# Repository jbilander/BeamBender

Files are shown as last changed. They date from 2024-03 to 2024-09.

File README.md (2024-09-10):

# BeamBender
An open source flicker fixer PCB for Amiga 1200 and 500 to be fitted under the floppy drive.

WORK IN PROGRESS, NOT FINISHED!!!

***

Rev. 1B
<br />
<a href="images/BeamBender_flicker-fixer_A1200-A500_pic11.jpg">
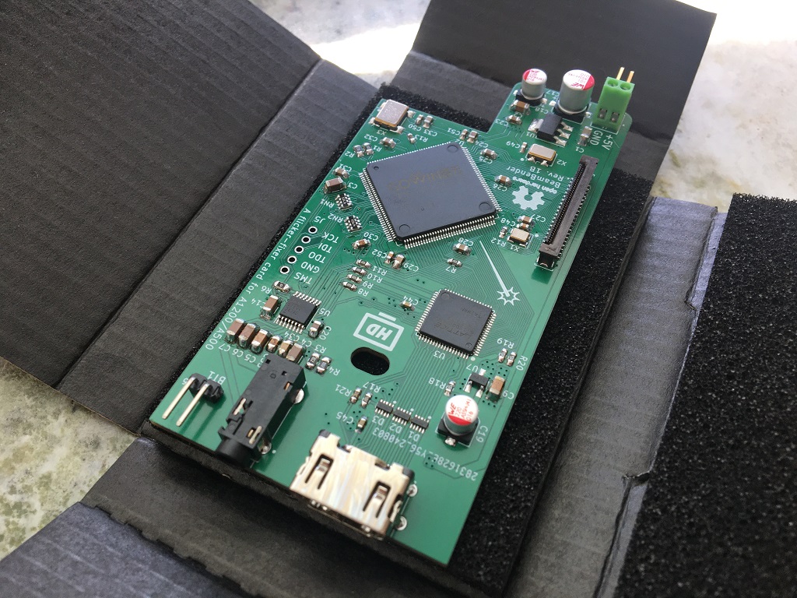
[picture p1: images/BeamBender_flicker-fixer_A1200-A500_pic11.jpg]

</a>
<a href="images/BeamBender_flicker-fixer_A1200-A500_pic12.jpg">
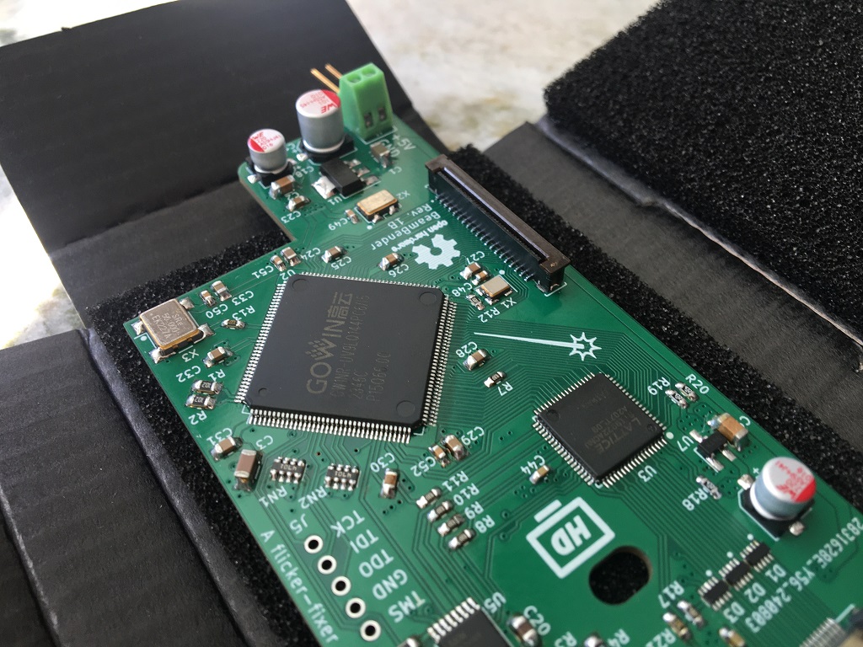
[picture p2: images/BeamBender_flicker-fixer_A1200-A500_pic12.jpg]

</a>
<br />
<a href="images/BeamBender_flicker-fixer_A1200-A500_pic13.jpg">
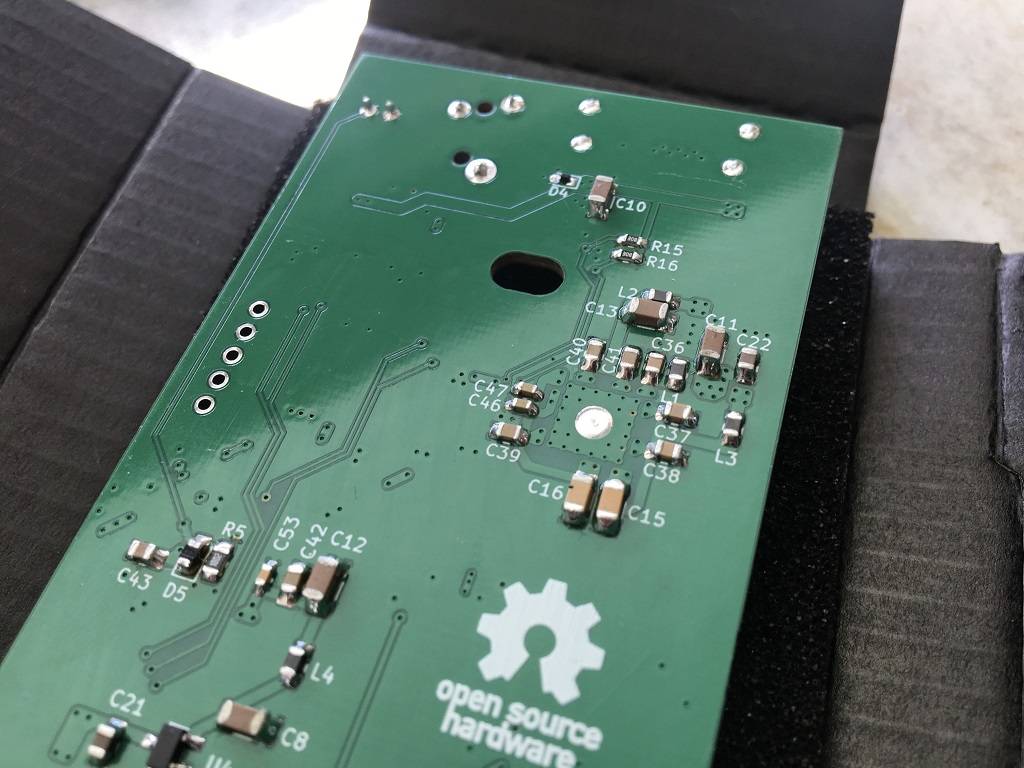
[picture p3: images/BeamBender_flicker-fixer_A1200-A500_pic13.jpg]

</a>
<a href="images/BeamBender_flicker-fixer_A1200-A500_pic14.jpg">
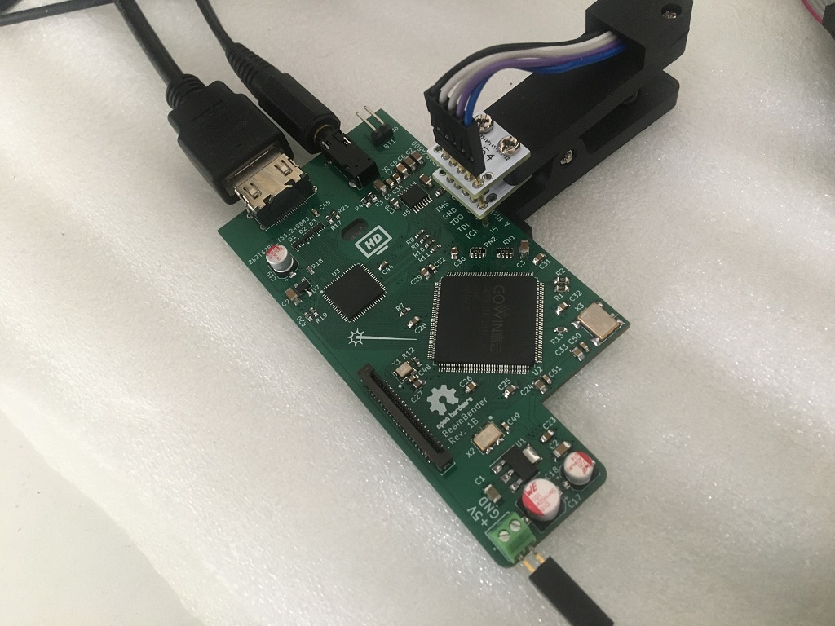
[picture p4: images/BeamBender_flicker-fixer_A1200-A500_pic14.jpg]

</a>

***

Rev. 1A
<br />
<a href="images/BeamBender_flicker-fixer_A1200-A500_pic1.png">
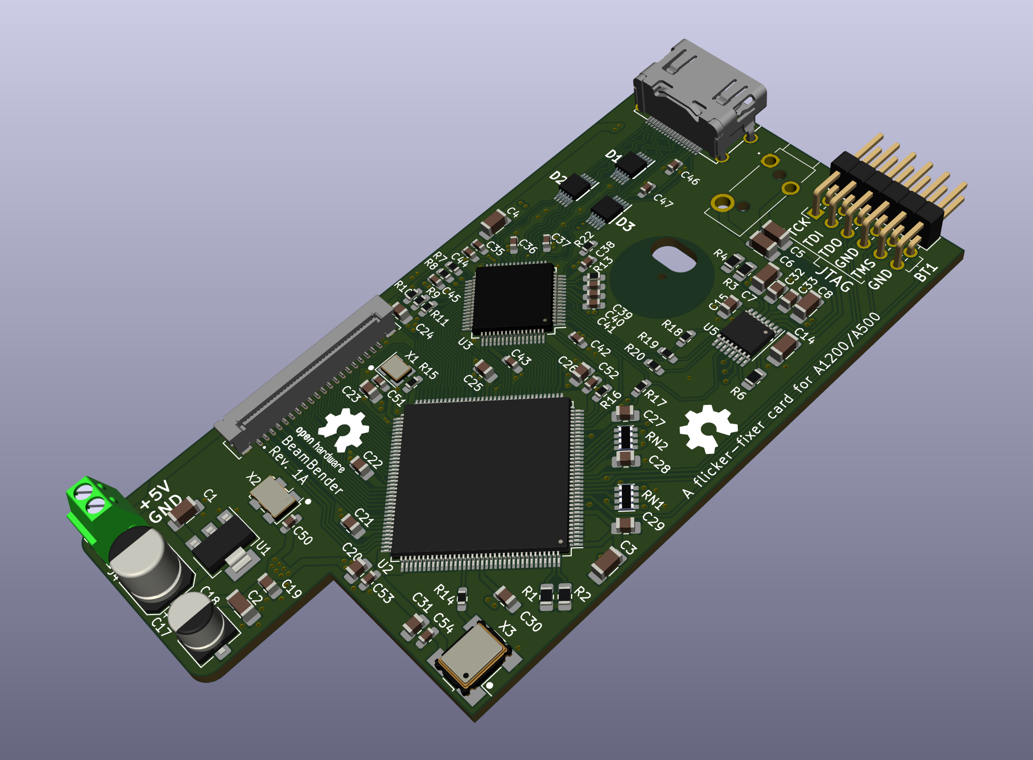
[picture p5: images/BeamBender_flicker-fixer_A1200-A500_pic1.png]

</a>
<br />
<a href="images/BeamBender_flicker-fixer_A1200-A500_pic2.png">
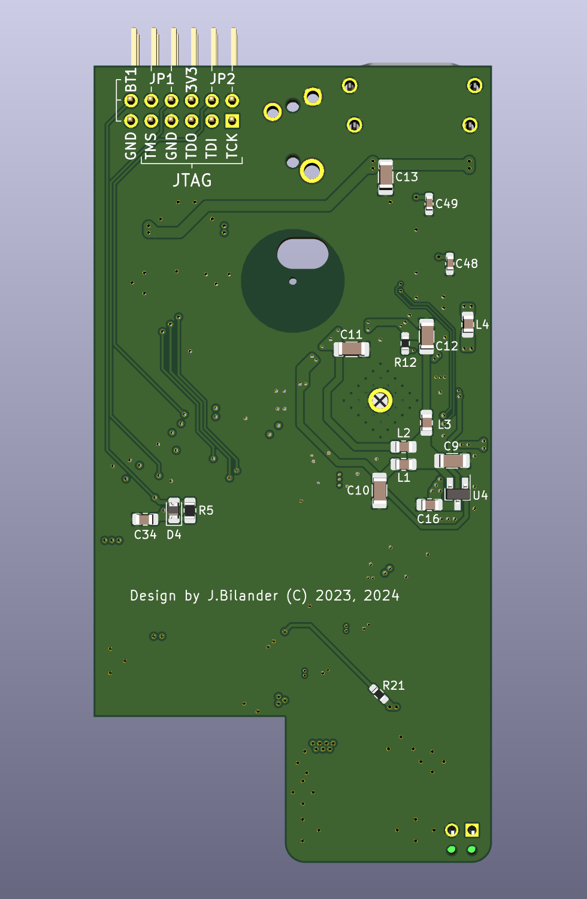
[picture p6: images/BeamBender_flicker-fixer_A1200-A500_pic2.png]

</a>
<br />
<a href="images/BeamBender_flicker-fixer_A1200-A500_pic3.jpg">
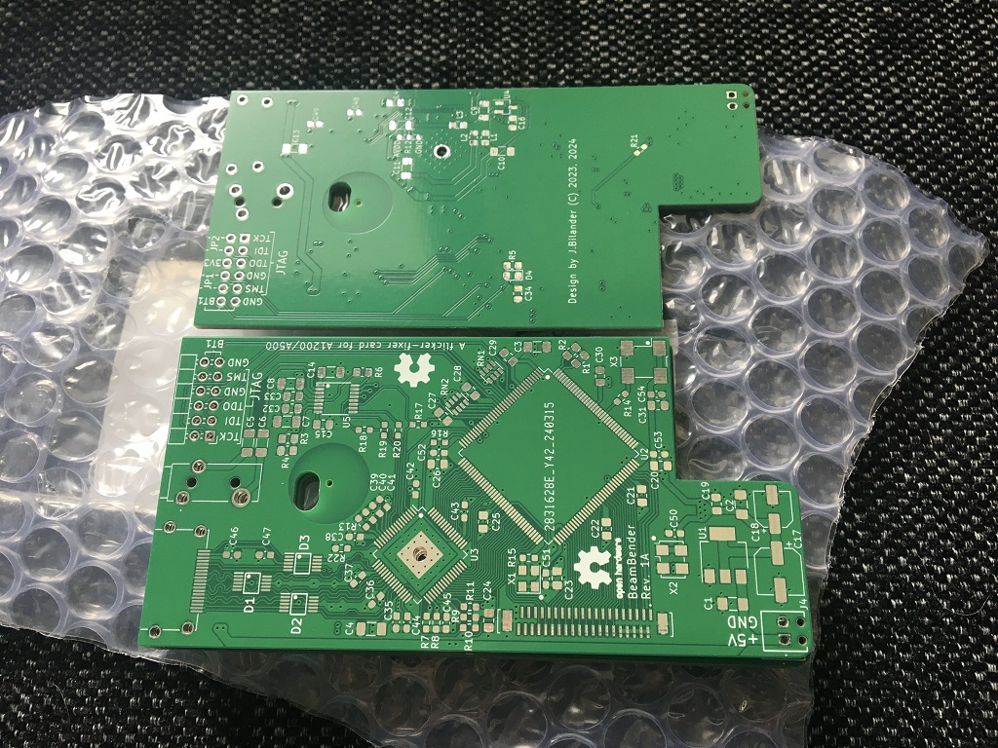
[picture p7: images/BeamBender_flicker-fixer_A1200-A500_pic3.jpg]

</a>
<br />
<a href="images/BeamBender_flicker-fixer_A1200-A500_pic4.jpg">
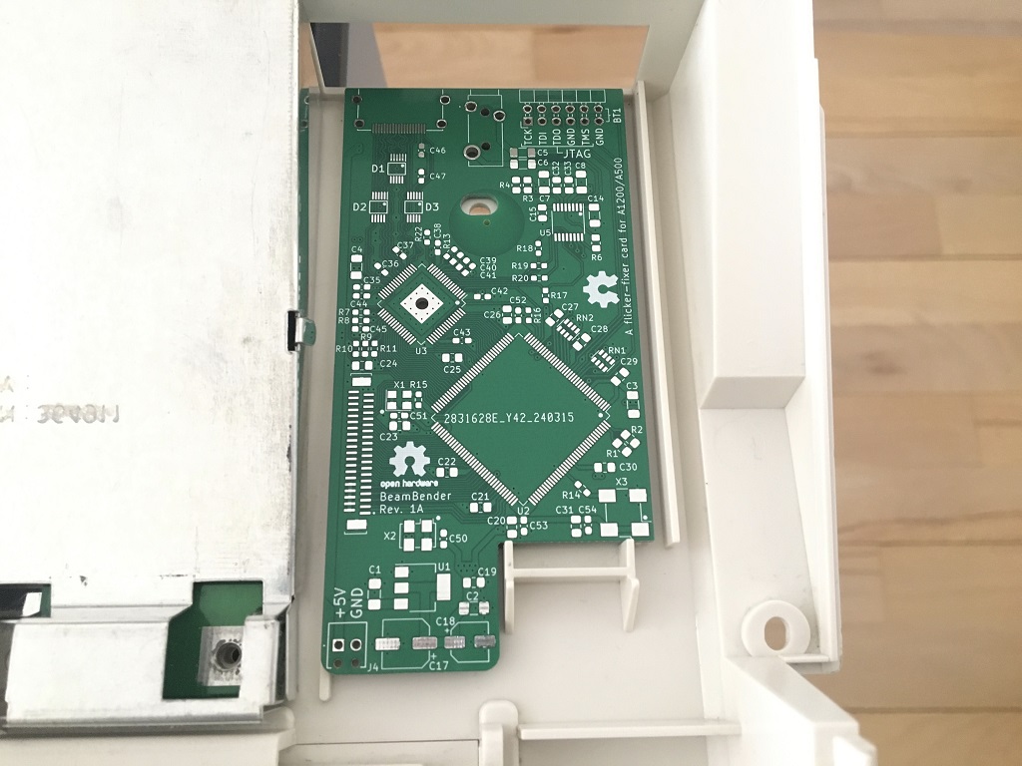
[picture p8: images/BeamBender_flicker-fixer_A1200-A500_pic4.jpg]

</a>
<br />
<a href="images/BeamBender_flicker-fixer_A1200-A500_pic5.jpg">
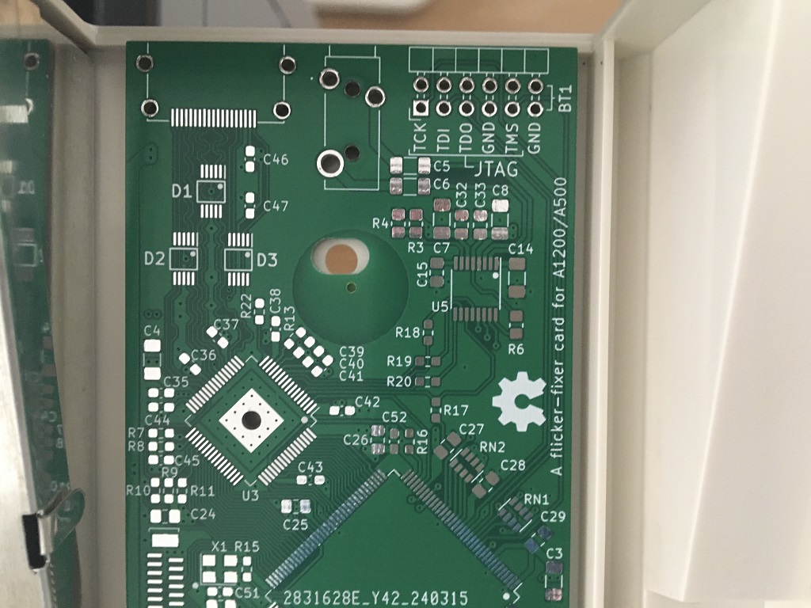
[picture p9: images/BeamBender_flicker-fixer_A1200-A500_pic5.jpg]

</a>
<a href="images/BeamBender_flicker-fixer_A1200-A500_pic6.jpg">
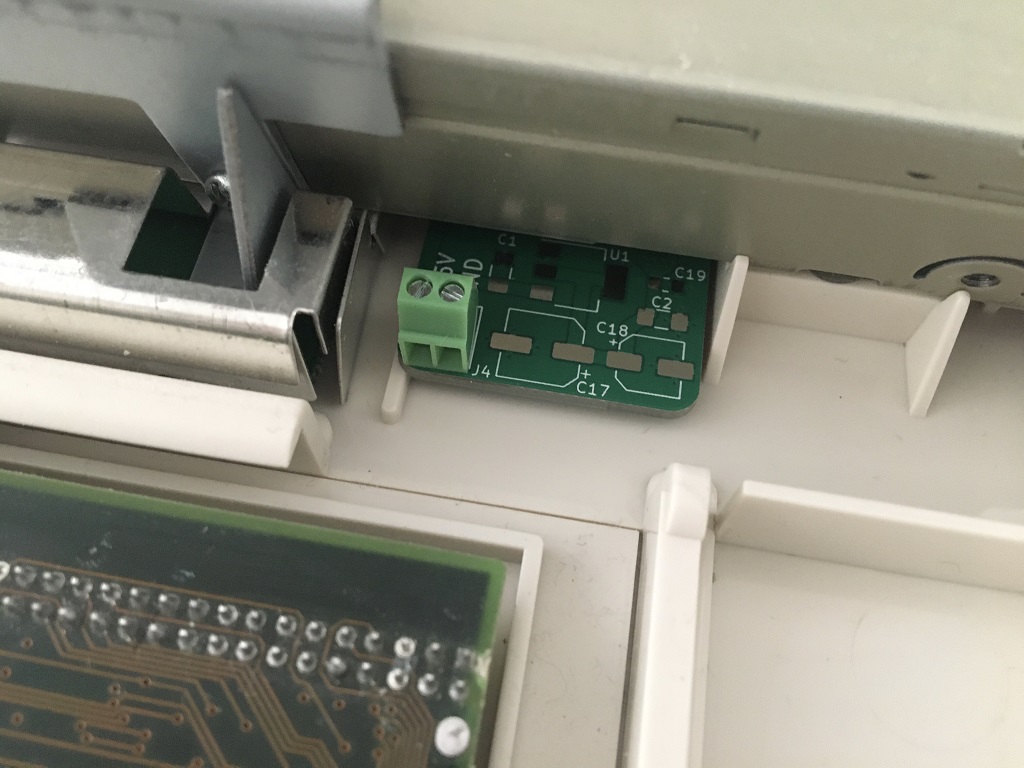
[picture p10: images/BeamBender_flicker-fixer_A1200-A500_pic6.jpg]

</a>
<br />
<a href="images/BeamBender_flicker-fixer_A1200-A500_pic7.jpg">
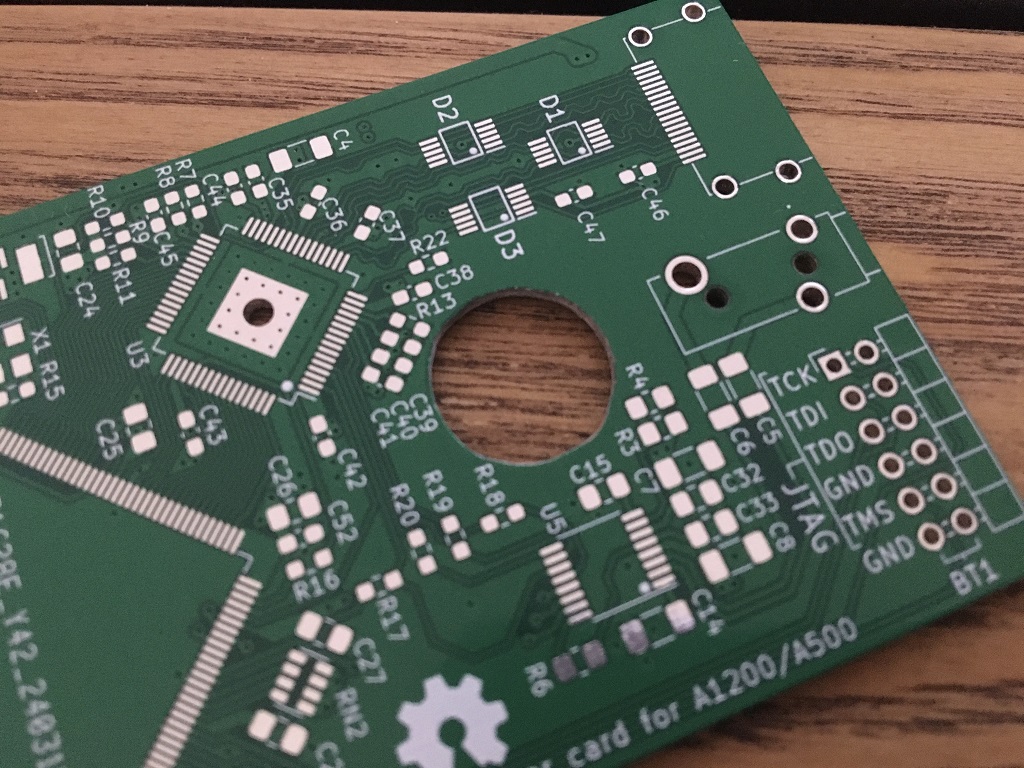
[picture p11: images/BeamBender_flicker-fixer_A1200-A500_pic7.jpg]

</a>
<a href="images/BeamBender_flicker-fixer_A1200-A500_pic8.jpg">
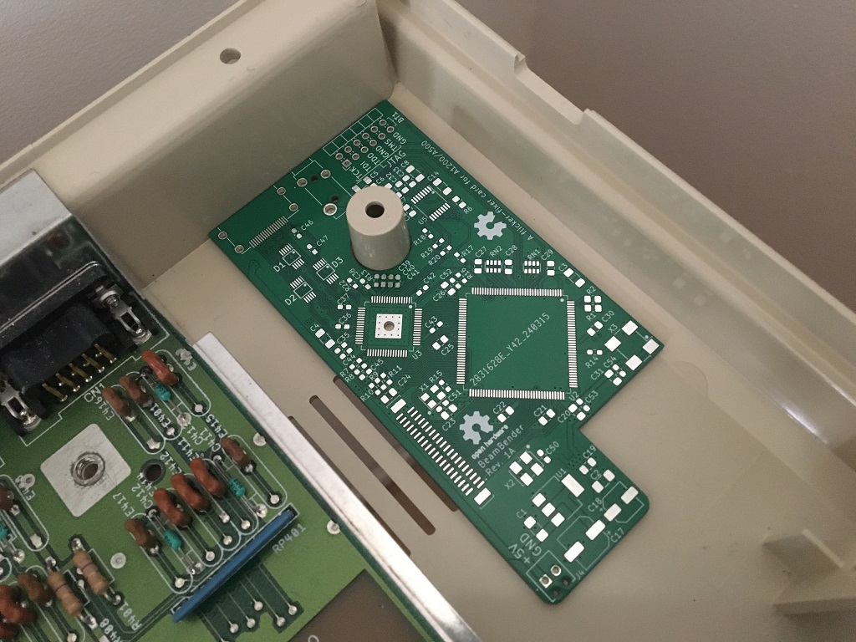
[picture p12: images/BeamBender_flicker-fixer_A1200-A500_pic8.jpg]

</a>
<br />
<a href="images/BeamBender_flicker-fixer_A1200-A500_pic9.jpg">
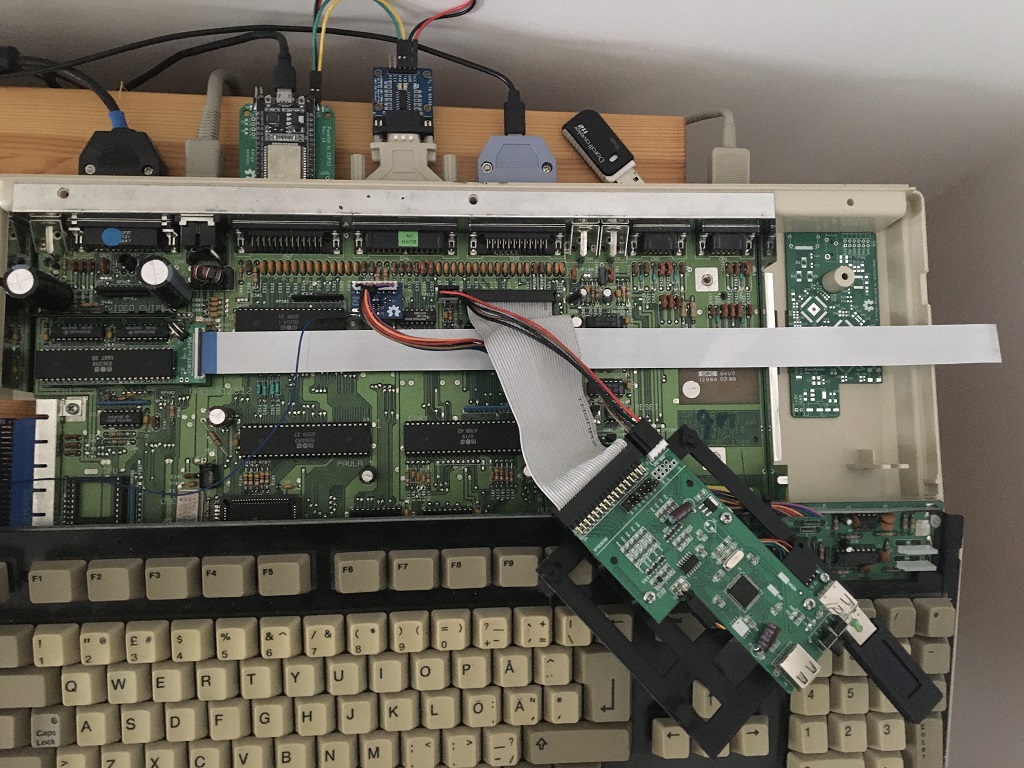
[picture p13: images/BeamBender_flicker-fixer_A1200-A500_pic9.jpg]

</a>
<a href="images/BeamBender_flicker-fixer_A1200-A500_pic10.jpg">
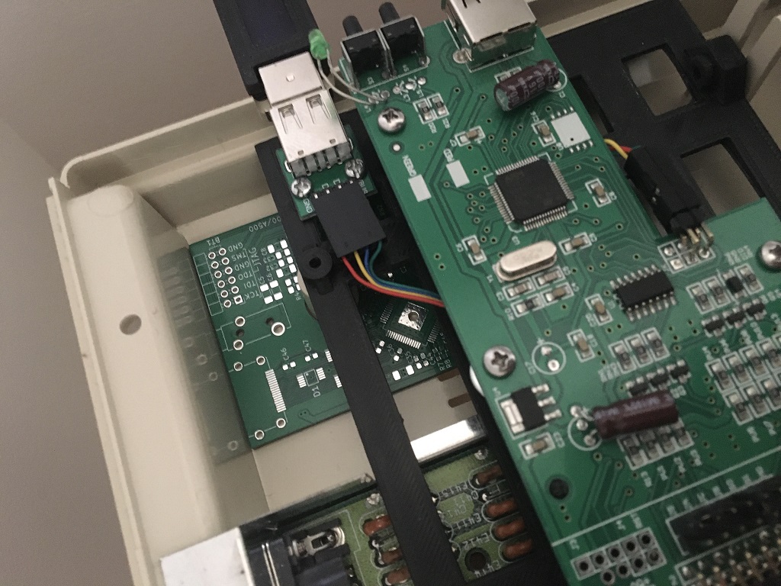
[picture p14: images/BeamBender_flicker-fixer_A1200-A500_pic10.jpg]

</a>

***

BOM Rev. 1B
---------
Designator  | Name/Value   | Package | Notes
-|-|-|-|
U1 | Voltage Regulator 3.3V, <br /> LM1117-3.3 or <br /> AMS1117-3.3 | SOT-223 | 3.3V 1A Low Drop-Out (LDO) Voltage regulator. https://www.aliexpress.com/item/32869037691.html
U2 | Gowin FPGA GW1NR-UV9LQ144PC6/I5 | LQFP-144 | FPGA - Field Programmable Gate Array, 8640 LE, 121 I/O, Embedded 64Mbit 16-bit PSRAM <br /> [GW1NR-UV9LQ144PC6/I5](https://www.mouser.com/ProductDetail/192-1NRUV9LQ144PC6I5)
U3 | SiI9022A | QFN-72-1EP_10x10mm_P0.5mm_EP4.7x4.7mm | 165 MHz High Performance HDMI Transmitter [SII9022ACNU](https://www.mouser.com/ProductDetail/842-SII9022ACNU)
U4 | Voltage Regulator 1.8V, <br /> MCP1702T-1802E/CB | SOT-23 | 1.8V Low Drop-Out (LDO) Voltage regulator. [MCP1702T1802E-CB](https://www.mouser.com/ProductDetail/579-MCP1702T1802E-CB)
U5 | Audio A/D Converter AK5720VT | TSSOP-16 | ADC IC 2ch 24bit 96K. [AK5720VT](https://www.mouser.se/ProductDetail/412-AK5720VT)
U6 | Voltage Regulator 1.2V, <br /> MCP1702T-1202E/CB | SOT-23 | 1.2V Low Drop-Out (LDO) Voltage regulator. [MCP1702T1202E-CB](https://eu.mouser.com/ProductDetail/579-MCP1702T1202E-CB)
X1 | Abracon ASE-27.000MHZ-L-R-T | XTAL OSC SMD 3.2 mm x 2.5 mm | Standard Clock Oscillator XO 27MHZ CMOS SMD [ASE-27.000MHZ-L-R-T](https://www.mouser.com/ProductDetail/815-ASE-27.000-LR-T)
X2 | Abracon ASFL1-24.576MHZ-EC-T | XTAL OSC SMD 5.0 mm x 3.2 mm | Standard Clock Oscillators 24.576 MHZ 15PF 3.3V [ASFL1-24.576MHZ-EC-T](https://www.mouser.com/ProductDetail/815-ASFL1-24.5-EC-T)
X3 | Standard Clock Oscillator 50 MHz, 3.3V LVCMOS | XTAL OSC SMD 7 mm x 5 mm | e.g. [FN5000109](https://www.mouser.com/ProductDetail/729-FN5000109) or [LH736050](https://www.mouser.com/ProductDetail/972-LH736050.000000I)
J1 | FFC & FPC Connectors .5 FPC VT ZIF Type-A | 40 Position FPC connector, Pitch 0.5 mm | [TE Connectivity 4-1734742-0](https://www.mouser.com/ProductDetail/571-4-1734742-0)
J2 | HDMI 1.4 Receptacle Connector 19 Position Surface Mount, Right Angle TH | HDMI Receptacle | [Amphenol 10029449-111RLF](https://www.mouser.com/ProductDetail/649-10029449-111RLF)
J3 | Phone Connectors 3.5 mm, Stereo | 3 Position Through Hole | [Kycon STX-3501-3N](https://www.mouser.com/ProductDetail/806-STX-3501-3N)
J4 | VCC/GND Phoenix Contact 2pin 2.54mm pitch | Fixed Terminal Blocks 2P 2.54mm 90DEG | VIN +5V <br /> Be careful with orientation, check polarity BEFORE connecting anything here. You can take +5V/GND from internal floppy pin-header on Amiga motherboard.<br />[1725656](https://www.mouser.com/ProductDetail/651-1725656) or [Aliexpress](https://www.aliexpress.com/item/1005001677869988.html)
D1-D3 | ESD Suppressors / TVS Diodes | U-DFN2510-10 | [D5V0F4U10LP-7](https://www.mouser.com/ProductDetail/621-D5V0F4U10LP-7)
D4 | ESD Suppressor / TVS Diode 1 Ch | SOD-723-2 | [SP1003-01DTG](https://www.mouser.com/ProductDetail/576-SP1003-01DTG) Optional ESD protection for VCC.
D5 | Diode - General Purpose | 0805 | e.g. [TS4148RBG](https://www.mouser.com/ProductDetail/821-TS4148RBG) Diode in RC-debounce (R5, C34) circuit for BT1 (Button 1).
L1-L4 | Ferrite Bead 600ohms 100MHz .5A Monolithic | 0805 | e.g. [HZ0805E601R-10](https://www.mouser.com/ProductDetail/875-HZ0805E601R-10)
C1-C13 | Capacitor 10uF | 1206 |
C14 | Capacitor 0.47uF | 1206 | e.g. [UMK316B7474KL-T](https://www.mouser.com/ProductDetail/963-UMK316B7474KL-T)
C15, C16 | Capacitor 0.1uF | 1206 |
C17 | Polarized Capacitor 100uF | CP_Elec_6.3x7.7 | e.g. [Wurth SMD WCAP-AS5H 100uF](https://www.mouser.com/ProductDetail/710-865230245004)
C18, C19 | Polarized Capacitor 22uF | CP_Elec_5x5.8 | e.g. [Wurth SMD WCAP-AS5H 22uF](https://www.mouser.com/ProductDetail/710-865230342002)
C20-C22 | Capacitor 1uF | 0805 |
C23-C43 | Capacitor 0.1uF = 100nF | 0805 |
C44-C47 | Capacitor 0.1uF = 100nF | 0603 |
C48-C53 | Capacitor 0.01uF = 10nF | 0603 |
R1-R3 | 1k Ω | 0805 |
R4, R5 | 10k Ω | 0805 |
R6 | 0-9 Ω or solder blob| 0805 | e.g. [CR0805-J/-000ELF](https://www.mouser.com/ProductDetail/652-CR0805-J-000ELF)
R7-R14 | 33 Ω | 0603 | e.g. [CR0603-FX-33R0ELF](https://www.mouser.com/ProductDetail/652-CR0603FX-33R0ELF)
R15, R16 | 2k Ω | 0603 | e.g. [CR0603-FX-2001ELF](https://www.mouser.com/ProductDetail/652-CR0603-FX-2001LF)
R17 | 4.3k Ω, 1% tolerance | 0603 | e.g. [CR0603-FX-4301ELF](https://www.mouser.com/ProductDetail/652-CR0603FX-4301ELF) The recommended value is 4.3k Ω ±1% with internal source termination enabled and 5.1k Ω ±1% without internal source termination. 
R18-R20 | 4.7k Ω | 0603 | 
R21 | 10k Ω | 0603 |
RN1, RN2 | CAY16A-4701F4LF RES ARRAY 4 Resistors 4.7k Ω | 1206 | [CAY16A-4701F4LF](https://eu.mouser.com/ProductDetail/652-CAY16A-4701F4LF)

***

[][cc-by-sa]

This work is licensed under a
[Creative Commons Attribution-ShareAlike 4.0 International License][cc-by-sa].

[][cc-by-sa]

[cc-by-sa]: http://creativecommons.org/licenses/by-sa/4.0/
[cc-by-sa-image]: https://licensebuttons.net/l/by-sa/4.0/88x31.png
[cc-by-sa-shield]: https://img.shields.io/badge/License-CC%20BY--SA%204.0-lightgrey.svg

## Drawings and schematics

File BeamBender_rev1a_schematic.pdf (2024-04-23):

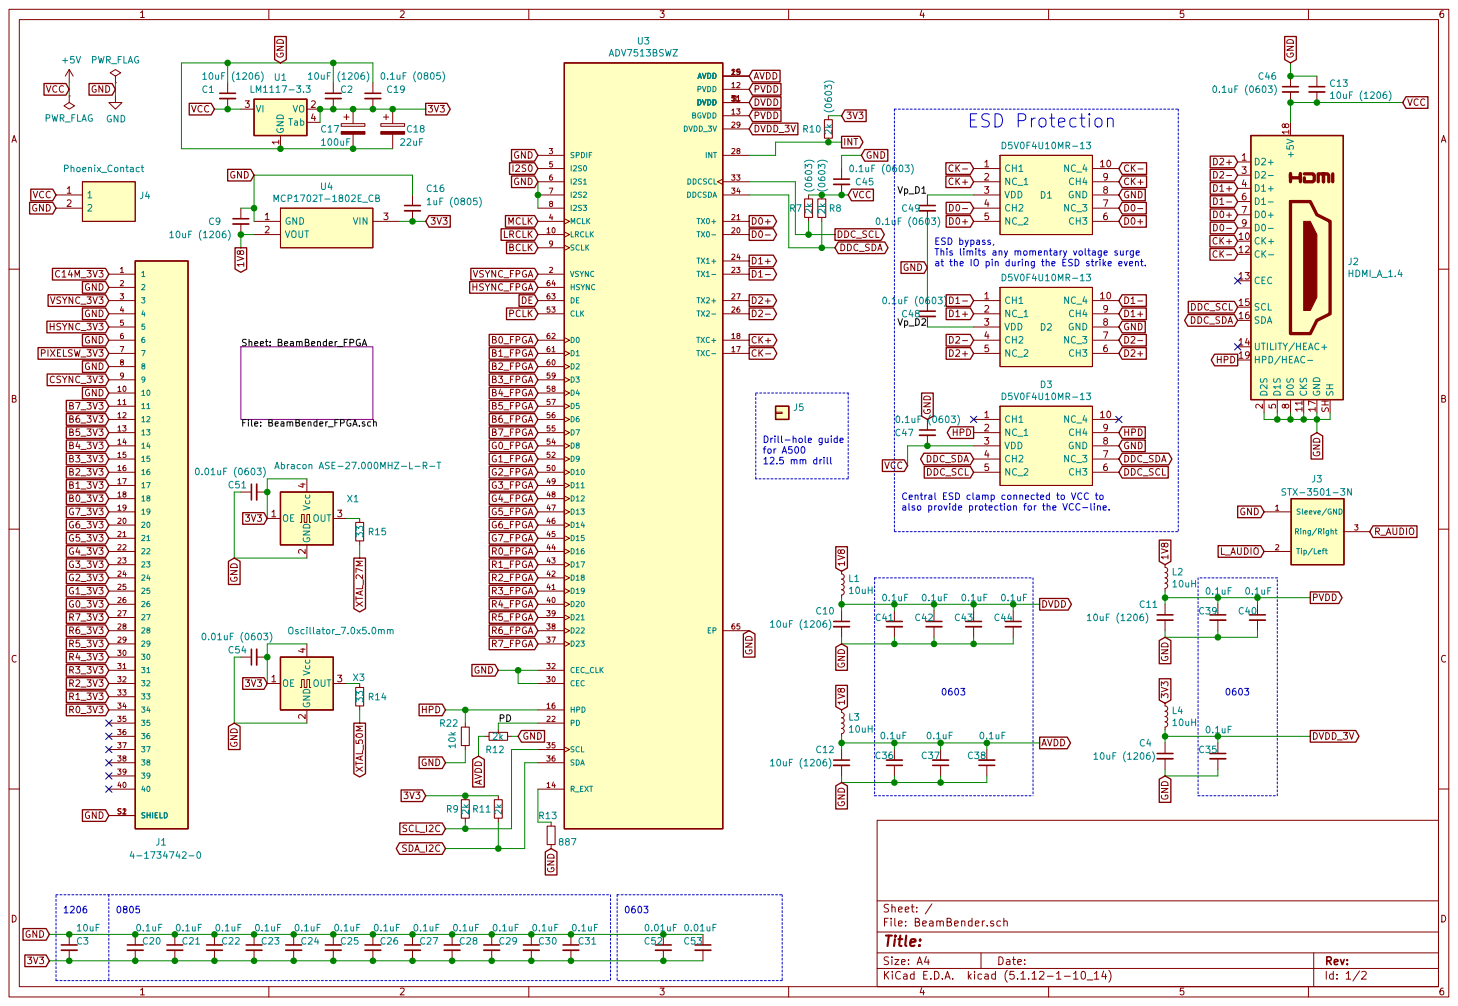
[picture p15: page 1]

This limits any momentary voltage surge
at the IO pin during the ESD strike event.
0.1uFC48

2 OUT 3 Vcc 4 X1 Abracon ASE-27.000MHZ-L-R-TC27

also provide protection for the VCC-line.

Id: 1/2 Title: File: BeamBender.sch Sheet: /

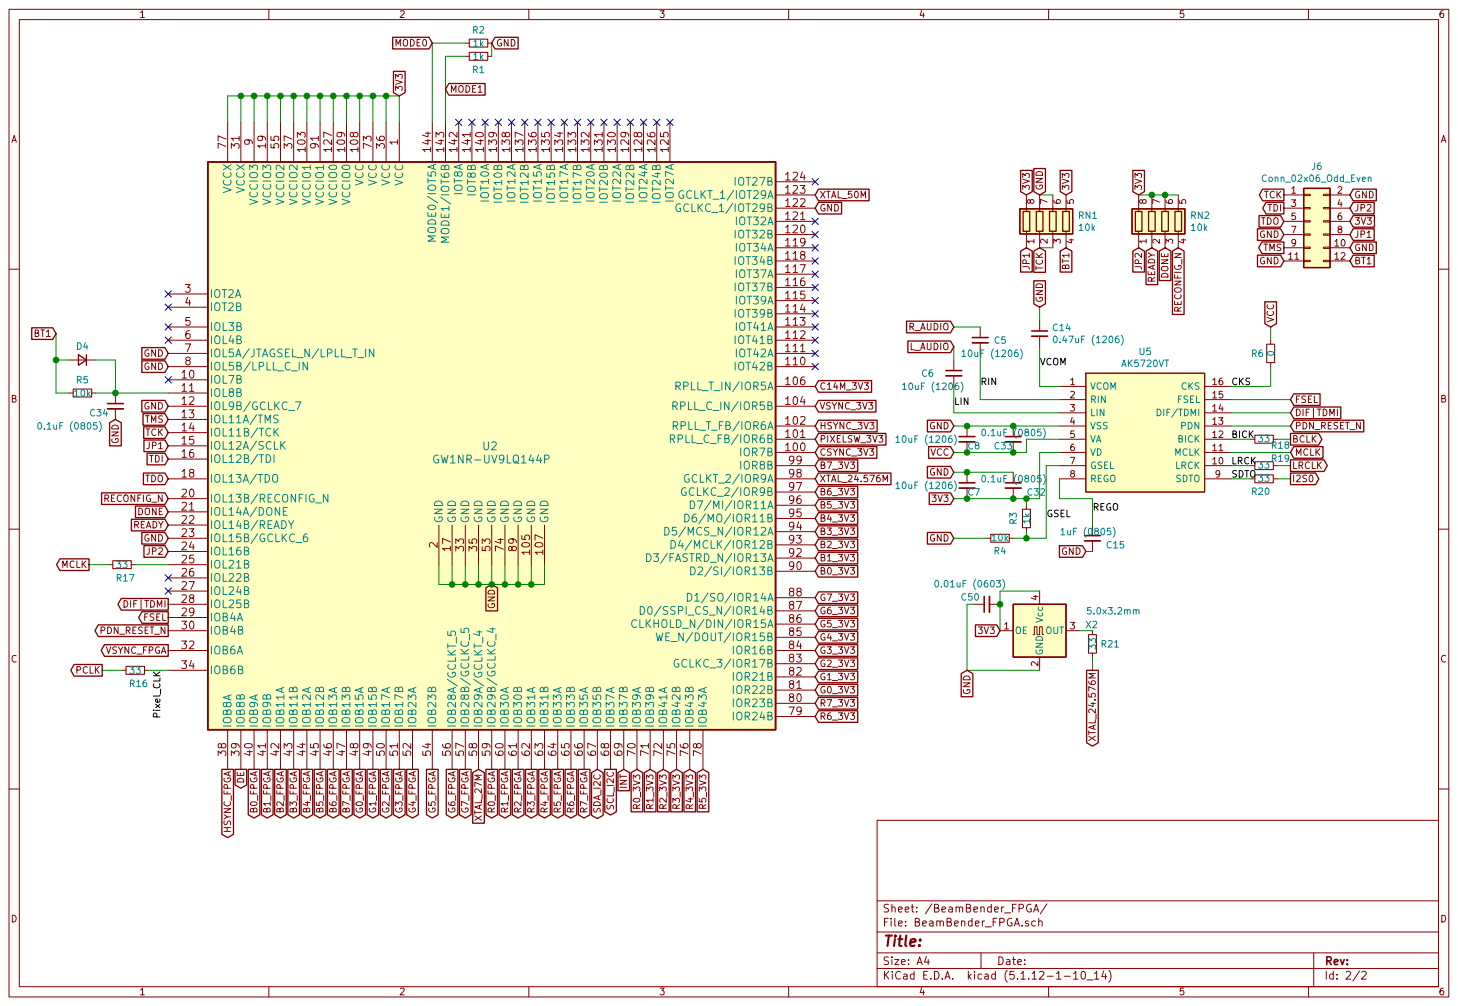
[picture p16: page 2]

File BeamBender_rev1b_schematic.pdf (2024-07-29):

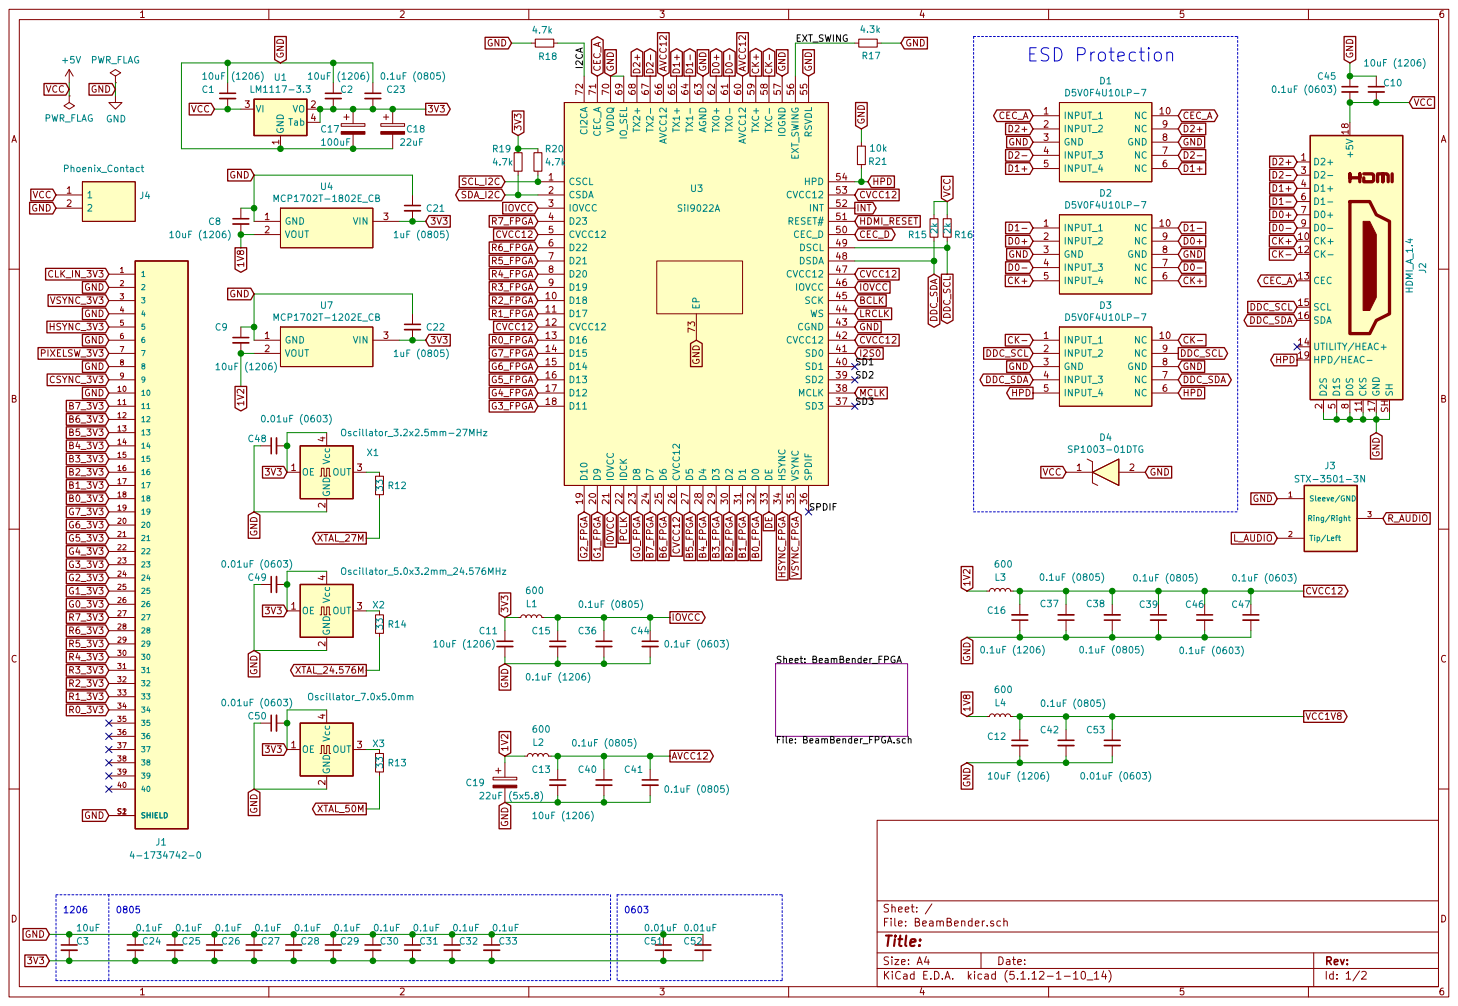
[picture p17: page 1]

Id: 1/2 Title: File: BeamBender.sch Sheet: / Sheet: BeamBender_FPGA

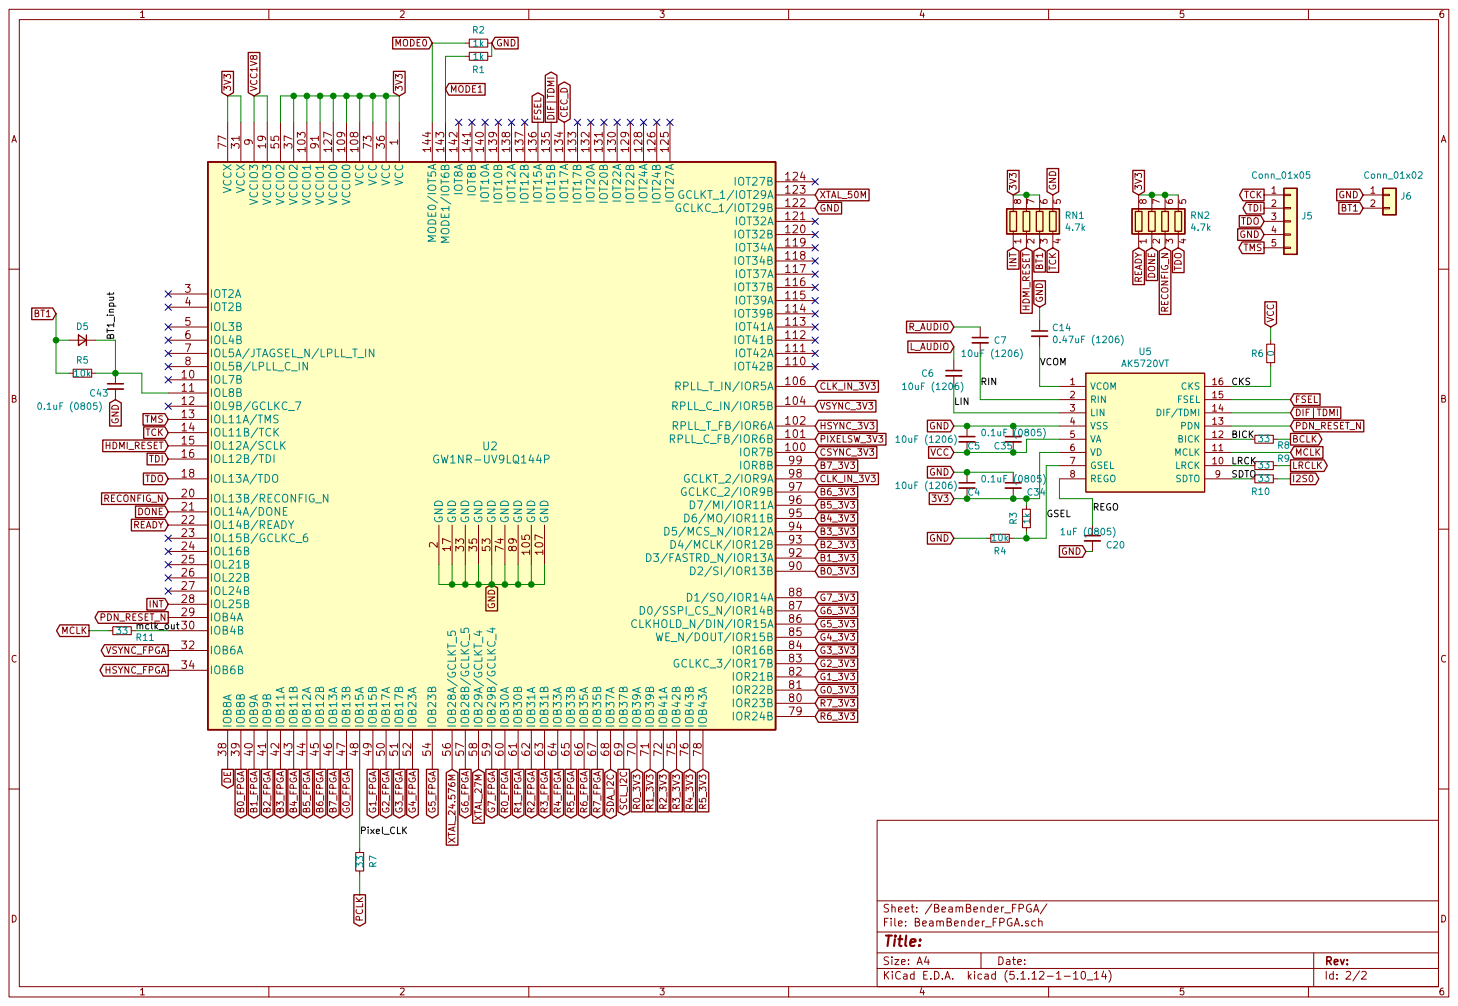
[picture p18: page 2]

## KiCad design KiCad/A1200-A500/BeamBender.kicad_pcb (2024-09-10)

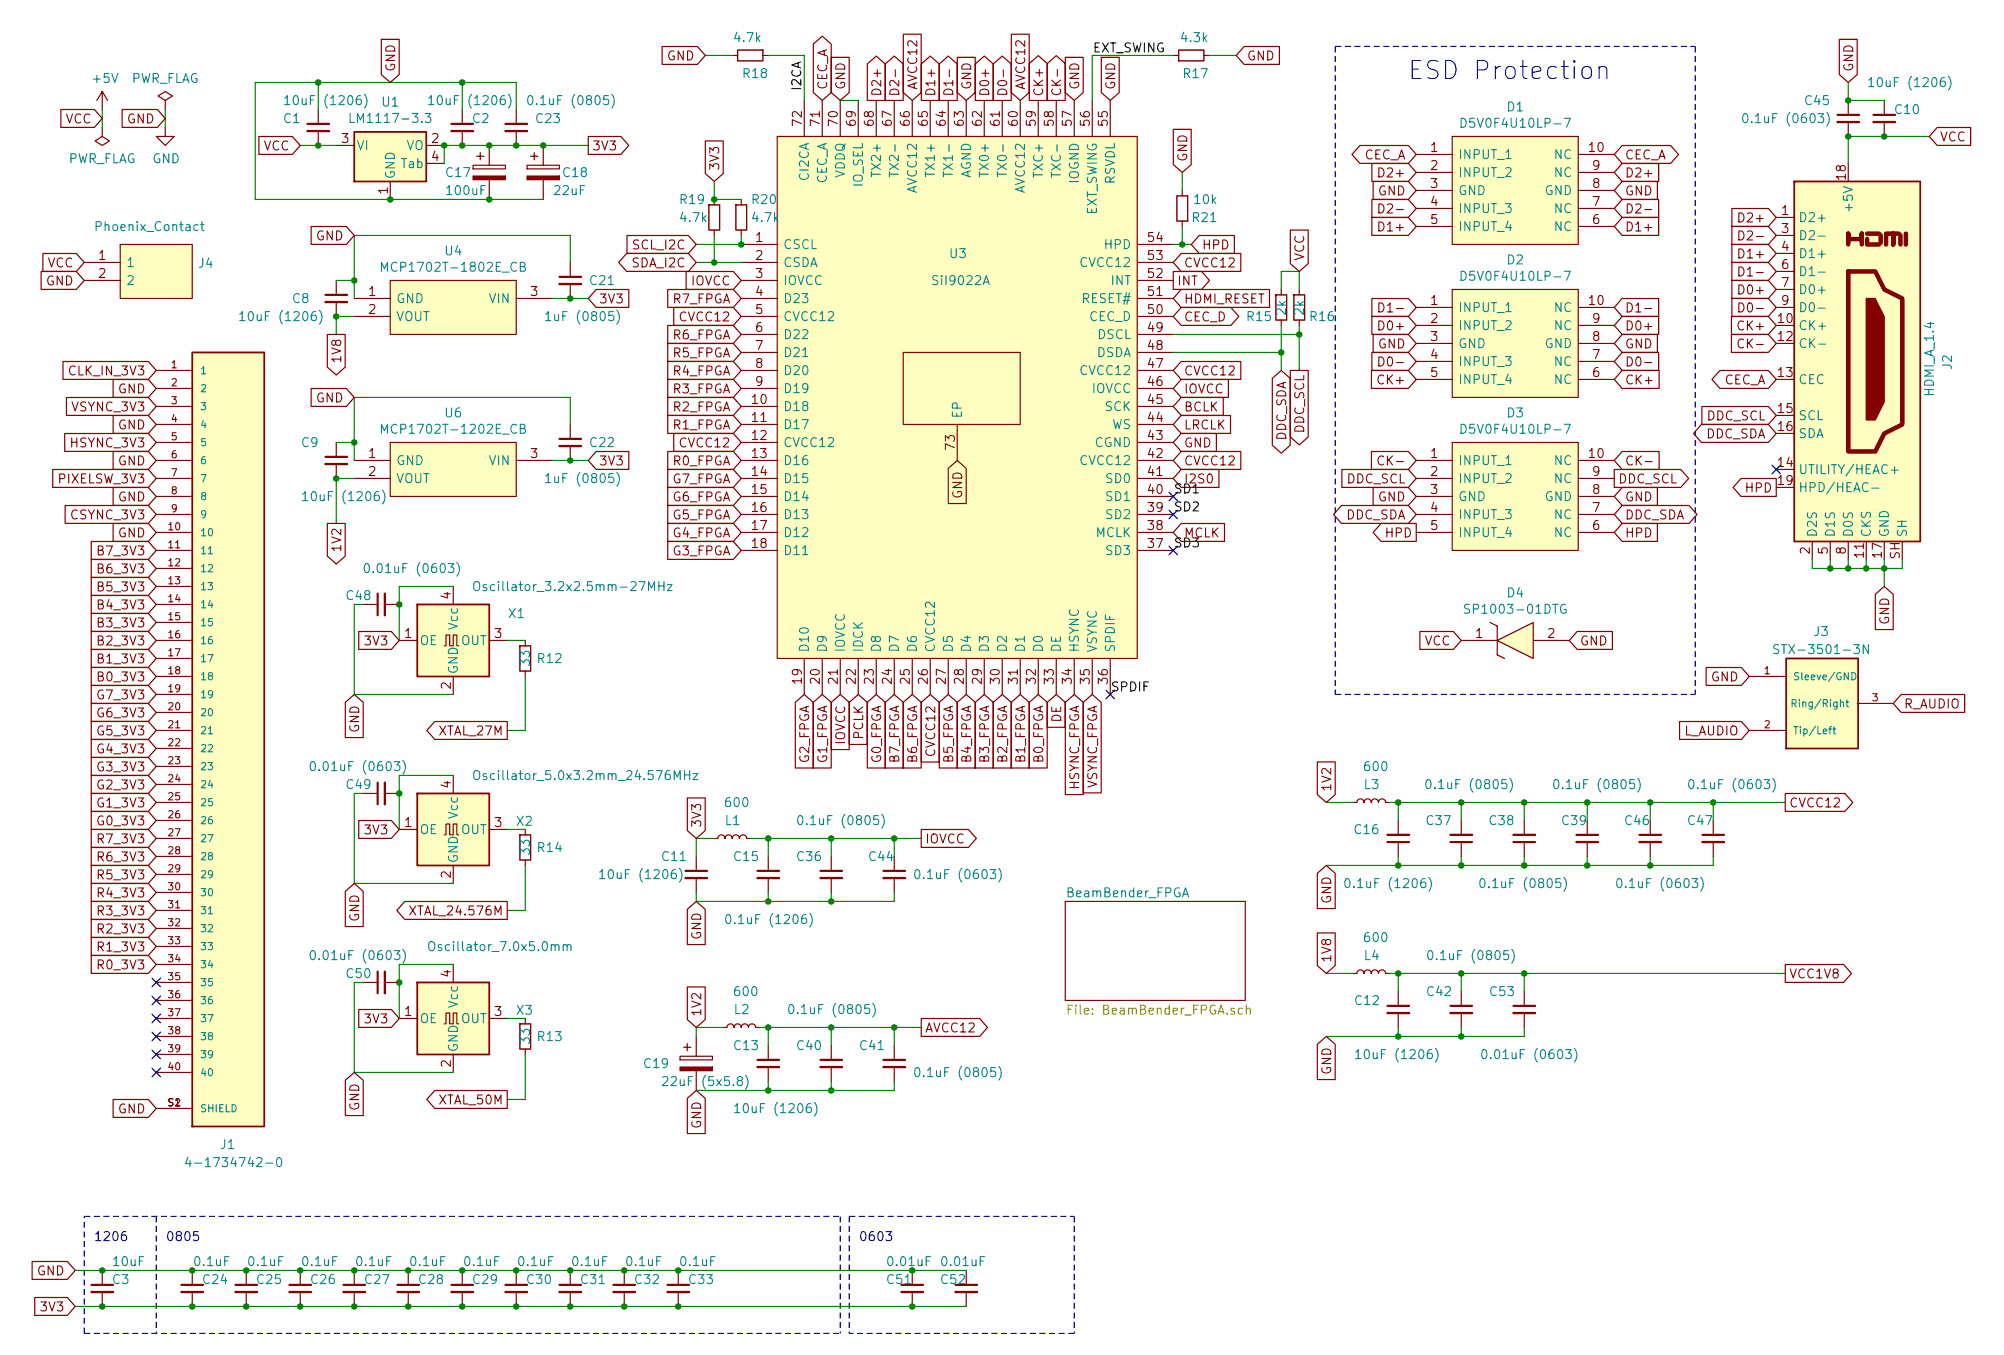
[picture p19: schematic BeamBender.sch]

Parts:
C1, C2: 10uF (1206); C_1206_3216Metric_Pad1.42x1.75mm_HandSolder
C3: 10uF; C_1206_3216Metric_Pad1.33x1.80mm_HandSolder
C8, C9, C10, C11, C12, C13: 10uF (1206); C_1206_3216Metric_Pad1.33x1.80mm_HandSolder
C15, C16: 0.1uF (1206); C_1206_3216Metric_Pad1.33x1.80mm_HandSolder
C17: 100uF; CP_Elec_6.3x7.7
C18: 22uF; CP_Elec_5x5.8
C19: 22uF (5x5.8); CP_Elec_5x5.8
C21, C22: 1uF (0805); C_0805_2012Metric_Pad1.18x1.45mm_HandSolder
C23: 0.1uF (0805); C_0805_2012Metric_Pad1.15x1.40mm_HandSolder
C24, C25, C26, C27, C28, C29, C30, C31, C32, C33: 0.1uF; C_0805_2012Metric_Pad1.18x1.45mm_HandSolder
C36, C37, C38, C39, C40, C41, C42: 0.1uF (0805); C_0805_2012Metric_Pad1.18x1.45mm_HandSolder
C44, C45, C46, C47: 0.1uF (0603); C_0603_1608Metric_Pad1.08x0.95mm_HandSolder
C48, C49, C50, C53: 0.01uF (0603); C_0603_1608Metric_Pad1.08x0.95mm_HandSolder
C51, C52: 0.01uF; C_0603_1608Metric_Pad1.08x0.95mm_HandSolder
D1, D2, D3: D5V0F4U10LP-7; Diodes_UDFN-10_1.0x2.5mm_P0.5mm_HandSolder
D4: SP1003-01DTG; D_0603_1608Metric
J1: 4-1734742-0; TE_4-1734742-0; PARTREV P
J2: HDMI_A_1.4; HDMI-10029449-111RLF
J3: STX-3501-3N; STX35013N
J4: Phoenix_Contact
L1, L2, L3, L4: 600; L_0805_2012Metric_Pad1.15x1.40mm_HandSolder
R12, R13, R14: 33; R_0603_1608Metric_Pad0.98x0.95mm_HandSolder
R15, R16: 2k; R_0603_1608Metric_Pad0.98x0.95mm_HandSolder
R17: 4.3k; R_0603_1608Metric_Pad0.98x0.95mm_HandSolder
R18, R19, R20: 4.7k; R_0603_1608Metric_Pad0.98x0.95mm_HandSolder
R21: 10k; R_0603_1608Metric_Pad0.98x0.95mm_HandSolder
U1: LM1117-3.3; SOT-223
U3: SiI9022A; QFN-72-1EP_10x10mm_P0.5mm_EP6x6mm_ThermalVias_HandSolder
U4: MCP1702T-1802E_CB; SOT-23_Handsoldering
U6: MCP1702T-1202E_CB; SOT-23_Handsoldering
X1: Oscillator_3.2x2.5mm-27MHz; Oscillator_SMD_SeikoEpson_SG8002CE-4Pin_3.2x2.5mm
X2: Oscillator_5.0x3.2mm_24.576MHz; Oscillator_SMD_TXC_7C-4Pin_5.0x3.2mm_HandSoldering
X3: Oscillator_7.0x5.0mm; Oscillator_SMD_SeikoEpson_SG8002CA-4Pin_7.0x5.0mm_HandSolde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

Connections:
1V2: C9.2, C19.1, L2.1, L3.1, U6.2 (VOUT)
1V8: C8.2, L4.1, U4.2 (VOUT)
3V3: C2.2, C3.2, C11.1, C17.1, C18.1, C21.2, C22.2, C23.2, C24.2, C25.2, C26.2, C27.2, C28.2, C29.2, C30.2, C31.2, C32.2, C33.2, C48.2, C49.2, C50.2, C51.2, C52.2, L1.1, R19.1, R20.1, U1.2 (VO), U1.4 (Tab), U4.3 (VIN), U6.3 (VIN), X1.1 (OE), X1.4 (Vcc), X2.1 (OE), X2.4 (Vcc), X3.1 (OE), X3.4 (Vcc); also elsewhere on the board
/EXT_SWING: R17.1, U3.56 (EXT_SWING)
/I2CA: R18.1, U3.72 (CI2CA)
/SD1: U3.40 (SD1)
/SD2: U3.39 (SD2)
/SD3: U3.37 (SD3)
/SPDIF: U3.36 (SPDIF)
AVCC12: C13.1, C40.1, C41.1, L2.2, U3.60 (AVCC12), U3.66 (AVCC12)
B0_3V3: J1.18; also elsewhere on the board
B0_FPGA: U3.32 (D0); also elsewhere on the board
B1_3V3: J1.17; also elsewhere on the board
B1_FPGA: U3.31 (D1); also elsewhere on the board
B2_3V3: J1.16; also elsewhere on the board
B2_FPGA: U3.30 (D2); also elsewhere on the board
B3_3V3: J1.15; also elsewhere on the board
B3_FPGA: U3.29 (D3); also elsewhere on the board
B4_3V3: J1.14; also elsewhere on the board
B4_FPGA: U3.28 (D4); also elsewhere on the board
B5_3V3: J1.13; also elsewhere on the board
B5_FPGA: U3.27 (D5); also elsewhere on the board
B6_3V3: J1.12; also elsewhere on the board
B6_FPGA: U3.25 (D6); also elsewhere on the board
B7_3V3: J1.11; also elsewhere on the board
B7_FPGA: U3.24 (D7); also elsewhere on the board
BCLK: U3.45 (SCK); also elsewhere on the board
CEC_A: D1.1 (INPUT_1), D1.10 (NC), J2.13 (CEC), U3.71 (CEC_A)
CEC_D: U3.50 (CEC_D); also elsewhere on the board
CK+: D2.5 (INPUT_4), D2.6 (NC), J2.10 (CK+), U3.59 (TXC+)
CK-: D3.1 (INPUT_1), D3.10 (NC), J2.12 (CK-), U3.58 (TXC-)
CLK_IN_3V3: J1.1; also elsewhere on the board
CSYNC_3V3: J1.9; also elsewhere on the board
CVCC12: C16.2, C37.2, C38.2, C39.1, C46.1, C47.1, L3.2, U3.5 (CVCC12), U3.12 (CVCC12), U3.26 (CVCC12), U3.42 (CVCC12), U3.47 (CVCC12), U3.53 (CVCC12)
D0+: D2.2 (INPUT_2), D2.9 (NC), J2.7 (D0+), U3.62 (TX0+)
D0-: D2.4 (INPUT_3), D2.7 (NC), J2.9 (D0-), U3.61 (TX0-)
D1+: D1.5 (INPUT_4), D1.6 (NC), J2.4 (D1+), U3.65 (TX1+)
D1-: D2.1 (INPUT_1), D2.10 (NC), J2.6 (D1-), U3.64 (TX1-)
D2+: D1.2 (INPUT_2), D1.9 (NC), J2.1 (D2+), U3.68 (TX2+)
D2-: D1.4 (INPUT_3), D1.7 (NC), J2.3 (D2-), U3.67 (TX2-)
DDC_SCL: D3.2 (INPUT_2), D3.9 (NC), J2.15 (SCL), R16.2, U3.49 (DSCL)
DDC_SDA: D3.4 (INPUT_3), D3.7 (NC), J2.16 (SDA), R15.2, U3.48 (DSDA)
DE: U3.33 (DE); also elsewhere on the board
G0_3V3: J1.26; also elsewhere on the board
G0_FPGA: U3.23 (D8); also elsewhere on the board
G1_3V3: J1.25; also elsewhere on the board
G1_FPGA: U3.20 (D9); also elsewhere on the board
G2_3V3: J1.24; also elsewhere on the board
G2_FPGA: U3.19 (D10); also elsewhere on the board
G3_3V3: J1.23; also elsewhere on the board
G3_FPGA: U3.18 (D11); also elsewhere on the board
G4_3V3: J1.22; also elsewhere on the board
G4_FPGA: U3.17 (D12); also elsewhere on the board
G5_3V3: J1.21; also elsewhere on the board
G5_FPGA: U3.16 (D13); also elsewhere on the board
G6_3V3: J1.20; also elsewhere on the board
G6_FPGA: U3.15 (D14); also elsewhere on the board
G7_3V3: J1.19; also elsewhere on the board
G7_FPGA: U3.14 (D15); also elsewhere on the board
GND: C1.1, C2.1, C3.1, C8.1, C9.1, C10.1, C11.2, C12.2, C13.2, C15.2, C16.1, C17.2, C18.2, C19.2, C21.1, C22.1, C23.1, C24.1, C25.1, C26.1, C27.1, C28.1, C29.1, C30.1, C31.1, C32.1, C33.1, C36.2, C37.1, C38.1, C39.2, C40.2, C41.2, C42.2, C44.2, C45.1, C46.2, C47.2, C48.1, C49.1, C50.1, C51.1, C52.1, C53.2, D1.3 (GND), D1.8 (GND), D2.3 (GND), D2.8 (GND), D3.3 (GND), D3.8 (GND), D4.2, J1.2, J1.4, J1.6, J1.8, J1.10, J1.S1 (SHIELD), J1.S2 (SHIELD), J2.2 (D2S), J2.5 (D1S), J2.8 (D0S), J2.11 (CKS), J2.17 (GND), J2.SH, J3.1 (Sleeve/GND), J4.2, R17.2, R18.2, R21.2, U1.1 (GND), U3.43 (CGND), U3.55 (RSVDL), U3.57 (IOGND), U3.63 (AGND), U3.69 (IO_SEL), U3.70 (VDDQ), U3.73 (EP), U4.1 (GND), U6.1 (GND), X1.2 (GND), X2.2 (GND), X3.2 (GND); also elsewhere on the board
HDMI_RESET: U3.51 (RESET#); also elsewhere on the board
HPD: D3.5 (INPUT_4), D3.6 (NC), J2.19 (HPD/HEAC-), R21.1, U3.54 (HPD)
HSYNC_3V3: J1.5; also elsewhere on the board
HSYNC_FPGA: U3.34 (HSYNC); also elsewhere on the board
I2S0: U3.41 (SD0); also elsewhere on the board
INT: U3.52 (INT); also elsewhere on the board
IOVCC: C15.1, C36.1, C44.1, L1.2, U3.3 (IOVCC), U3.21 (IOVCC), U3.46 (IOVCC)
LRCLK: U3.44 (WS); also elsewhere on the board
L_AUDIO: J3.2 (Tip/Left); also elsewhere on the board
MCLK: U3.38 (MCLK); also elsewhere on the board
unnamed: R12.1, X1.3 (OUT)
unnamed: R13.1, X3.3 (OUT)
unnamed: R14.1, X2.3 (OUT)
PCLK: U3.22 (IDCK); also elsewhere on the board
PIXELSW_3V3: J1.7; also elsewhere on the board
R0_3V3: J1.34; also elsewhere on the board
R0_FPGA: U3.13 (D16); also elsewhere on the board
R1_3V3: J1.33; also elsewhere on the board
R1_FPGA: U3.11 (D17); also elsewhere on the board
R2_3V3: J1.32; also elsewhere on the board
R2_FPGA: U3.10 (D18); also elsewhere on the board
R3_3V3: J1.31; also elsewhere on the board
R3_FPGA: U3.9 (D19); also elsewhere on the board
R4_3V3: J1.30; also elsewhere on the board
R4_FPGA: U3.8 (D20); also elsewhere on the board
R5_3V3: J1.29; also elsewhere on the board
R5_FPGA: U3.7 (D21); also elsewhere on the board
R6_3V3: J1.28; also elsewhere on the board
R6_FPGA: U3.6 (D22); also elsewhere on the board
R7_3V3: J1.27; also elsewhere on the board
R7_FPGA: U3.4 (D23); also elsewhere on the board
R_AUDIO: J3.3 (Ring/Right); also elsewhere on the board
SCL_I2C: R20.2, U3.1 (CSCL); also elsewhere on the board
SDA_I2C: R19.2, U3.2 (CSDA); also elsewhere on the board
VCC: C1.2, C10.2, C45.2, D4.1, J2.18 (+5V), J4.1, R15.1, R16.1, U1.3 (VI); also elsewhere on the board
VCC1V8: C12.1, C42.1, C53.1, L4.2; also elsewhere on the board
VSYNC_3V3: J1.3; also elsewhere on the board
VSYNC_FPGA: U3.35 (VSYNC); also elsewhere on the board
XTAL_24.576M: R14.2; also elsewhere on the board
XTAL_27M: R12.2; also elsewhere on the board
XTAL_50M: R13.2; also elsewhere on the board

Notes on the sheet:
ESD Protection
0805
0603
1206

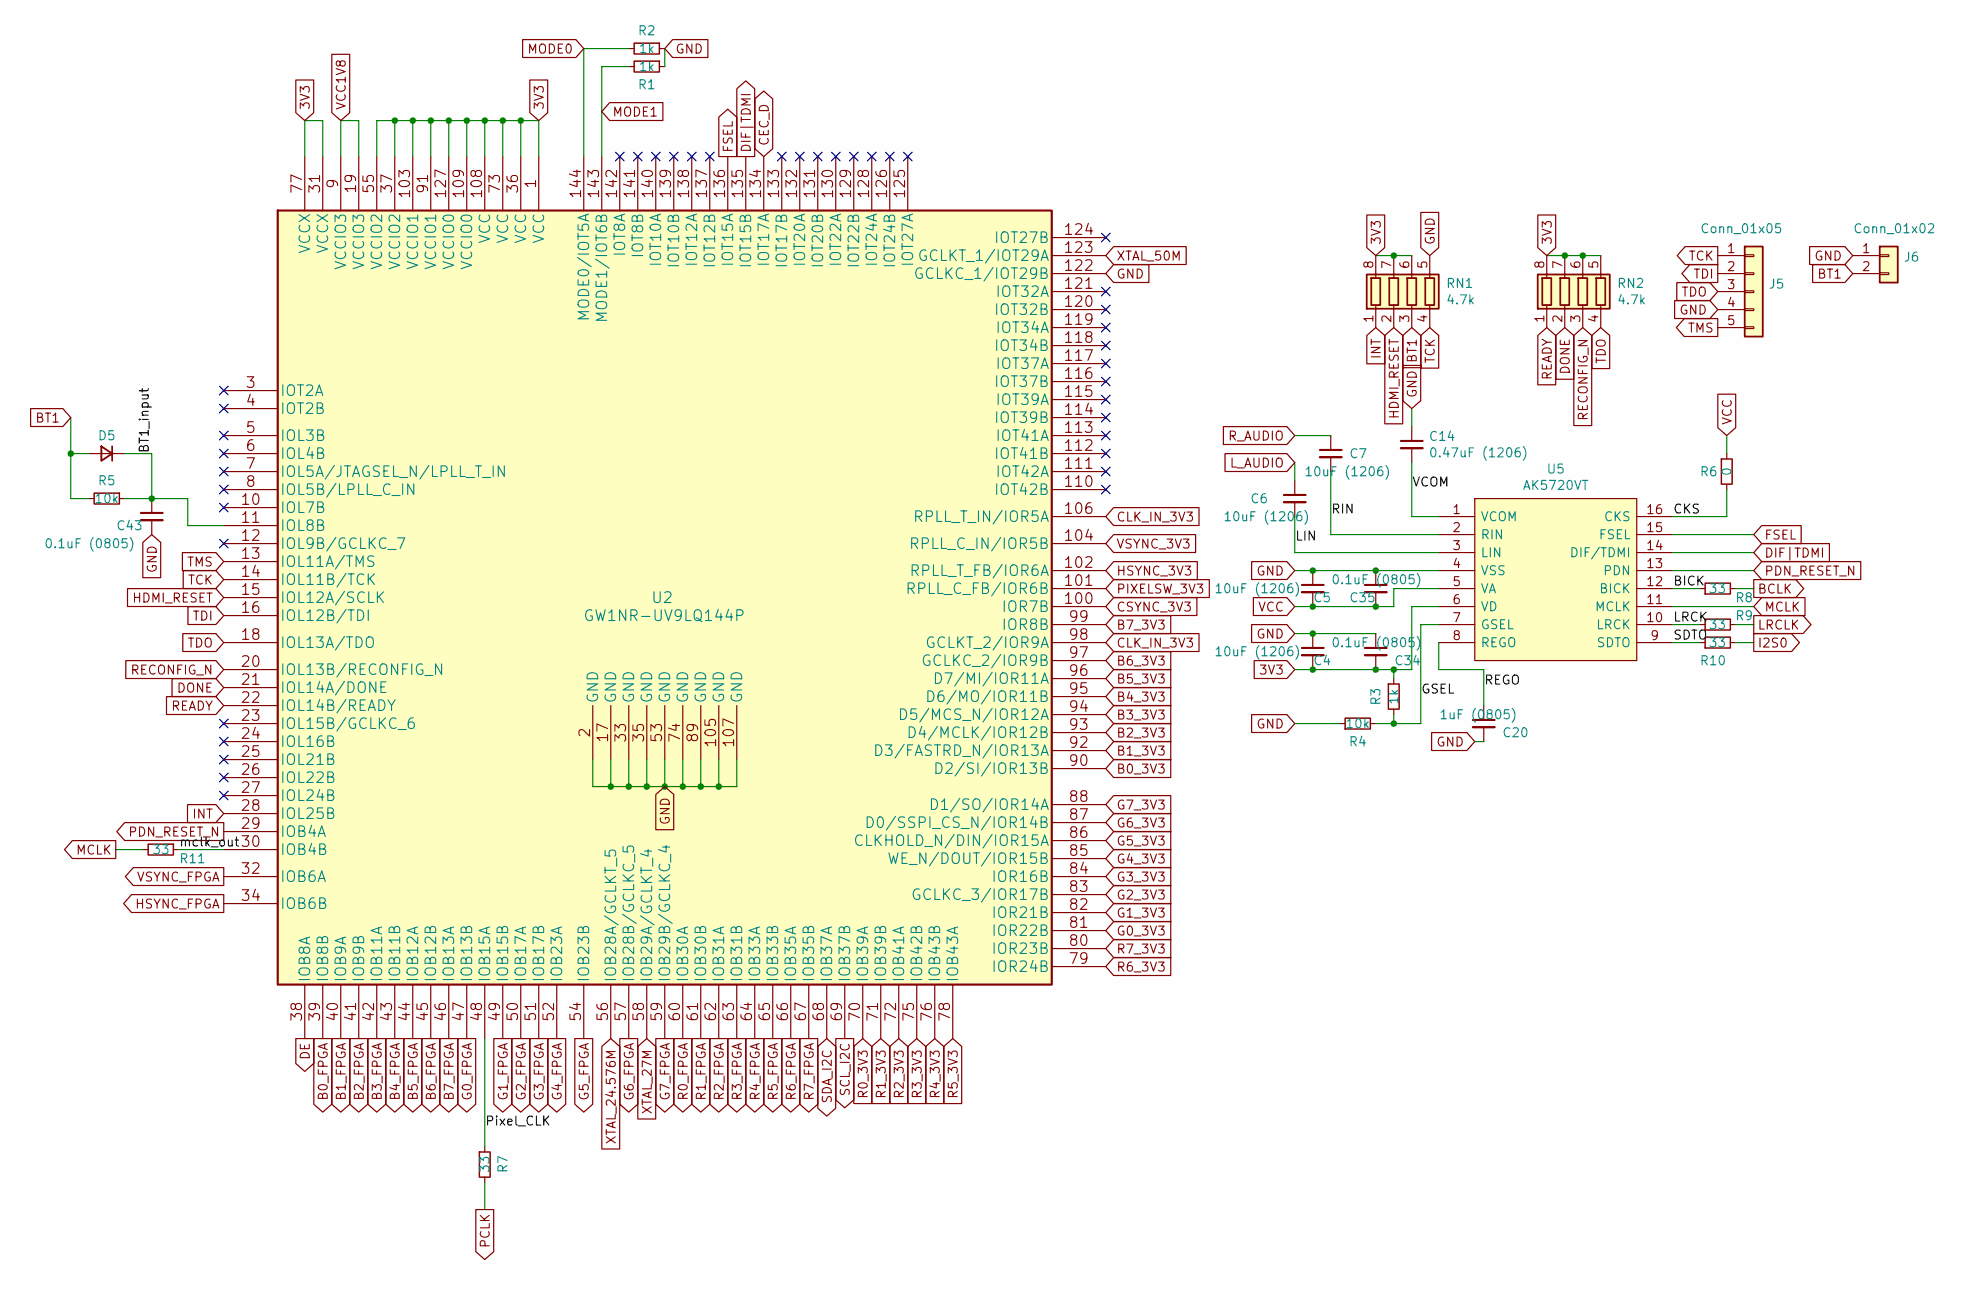
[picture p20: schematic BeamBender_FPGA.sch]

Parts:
C4, C5, C6, C7: 10uF (1206); C_1206_3216Metric_Pad1.33x1.80mm_HandSolder
C14: 0.47uF (1206); C_1206_3216Metric_Pad1.33x1.80mm_HandSolder
C20: 1uF (0805); C_0805_2012Metric_Pad1.18x1.45mm_HandSolder
C34, C35, C43: 0.1uF (0805); C_0805_2012Metric_Pad1.18x1.45mm_HandSolder
D5: D_Small; D_0805_2012Metric_Pad1.15x1.40mm_HandSolder
J5: Conn_01x05; PinHeader_1x05_P2.54mm_Vertical
J6: Conn_01x02; PinHeader_1x02_P2.54mm_Vertical
R1, R2, R3: 1k; R_0805_2012Metric_Pad1.20x1.40mm_HandSolder
R4, R5: 10k; R_0805_2012Metric_Pad1.20x1.40mm_HandSolder
R6: 0; R_0805_2012Metric_Pad1.20x1.40mm_HandSolder
R7, R8, R9, R10, R11: 33; R_0603_1608Metric_Pad0.98x0.95mm_HandSolder
RN1, RN2: 4.7k; RESCAF80P320X160X60-8N
U2: GW1NR-UV9LQ144P; LQFP-144_20x20mm_P0.5mm
U5: AK5720VT; TSSOP-16_4.4x5mm_P0.65mm

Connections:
3V3: C4.2, C34.2, R3.1, RN1.6 (R3.2), RN1.7 (R2.2), RN1.8 (R1.2), RN2.5 (R4.2), RN2.6 (R3.2), RN2.7 (R2.2), RN2.8 (R1.2), U2.1 (VCC), U2.31 (VCCX), U2.36 (VCC), U2.37 (VCCIO2), U2.55 (VCCIO2), U2.73 (VCC), U2.77 (VCCX), U2.91 (VCCIO1), U2.103 (VCCIO1), U2.108 (VCC), U2.109 (VCCIO0), U2.127 (VCCIO0), U5.6 (VD); also elsewhere on the board
/BeamBender_FPGA/BICK: R8.1, U5.12 (BICK)
/BeamBender_FPGA/BT1_input: C43.1, D5.1 (K), R5.1, U2.11 (IOL8B)
/BeamBender_FPGA/CKS: R6.2, U5.16 (CKS)
/BeamBender_FPGA/GSEL: R3.2, R4.2, U5.7 (GSEL)
/BeamBender_FPGA/LIN: C6.2, U5.3 (LIN)
/BeamBender_FPGA/LRCK: R9.1, U5.10 (LRCK)
/BeamBender_FPGA/Pixel_CLK: R7.1, U2.48 (IOB15A)
/BeamBender_FPGA/REGO: C20.1, U5.8 (REGO)
/BeamBender_FPGA/RIN: C7.2, U5.2 (RIN)
/BeamBender_FPGA/SDTO: R10.1, U5.9 (SDTO)
/BeamBender_FPGA/VCOM: C14.2, U5.1 (VCOM)
/BeamBender_FPGA/mclk_out: R11.1, U2.30 (IOB4B)
B0_3V3: U2.90 (D2/SI/IOR13B); also elsewhere on the board
B0_FPGA: U2.39 (IOB8B); also elsewhere on the board
B1_3V3: U2.92 (D3/FASTRD_N/IOR13A); also elsewhere on the board
B1_FPGA: U2.40 (IOB9A); also elsewhere on the board
B2_3V3: U2.93 (D4/MCLK/IOR12B); also elsewhere on the board
B2_FPGA: U2.41 (IOB9B); also elsewhere on the board
B3_3V3: U2.94 (D5/MCS_N/IOR12A); also elsewhere on the board
B3_FPGA: U2.42 (IOB11A); also elsewhere on the board
B4_3V3: U2.95 (D6/MO/IOR11B); also elsewhere on the board
B4_FPGA: U2.43 (IOB11B); also elsewhere on the board
B5_3V3: U2.96 (D7/MI/IOR11A); also elsewhere on the board
B5_FPGA: U2.44 (IOB12A); also elsewhere on the board
B6_3V3: U2.97 (GCLKC_2/IOR9B); also elsewhere on the board
B6_FPGA: U2.45 (IOB12B); also elsewhere on the board
B7_3V3: U2.99 (IOR8B); also elsewhere on the board
B7_FPGA: U2.46 (IOB13A); also elsewhere on the board
BCLK: R8.2; also elsewhere on the board
BT1: D5.2 (A), J6.2, R5.2, RN1.3 (R3.1)
CEC_D: U2.134 (IOT17A); also elsewhere on the board
CLK_IN_3V3: U2.98 (GCLKT_2/IOR9A), U2.106 (RPLL_T_IN/IOR5A); also elsewhere on the board
CSYNC_3V3: U2.100 (IOR7B); also elsewhere on the board
DE: U2.38 (IOB8A); also elsewhere on the board
DIF|TDMI: U2.135 (IOT15B), U5.14 (DIF/TDMI)
DONE: RN2.2 (R2.1), U2.21 (IOL14A/DONE)
FSEL: U2.136 (IOT15A), U5.15 (FSEL)
G0_3V3: U2.81 (IOR22B); also elsewhere on the board
G0_FPGA: U2.47 (IOB13B); also elsewhere on the board
G1_3V3: U2.82 (IOR21B); also elsewhere on the board
G1_FPGA: U2.49 (IOB15B); also elsewhere on the board
G2_3V3: U2.83 (GCLKC_3/IOR17B); also elsewhere on the board
G2_FPGA: U2.50 (IOB17A); also elsewhere on the board
G3_3V3: U2.84 (IOR16B); also elsewhere on the board
G3_FPGA: U2.51 (IOB17B); also elsewhere on the board
G4_3V3: U2.85 (WE_N/DOUT/IOR15B); also elsewhere on the board
G4_FPGA: U2.52 (IOB23A); also elsewhere on the board
G5_3V3: U2.86 (CLKHOLD_N/DIN/IOR15A); also elsewhere on the board
G5_FPGA: U2.54 (IOB23B); also elsewhere on the board
G6_3V3: U2.87 (D0/SSPI_CS_N/IOR14B); also elsewhere on the board
G6_FPGA: U2.57 (IOB28B/GCLKC_5); also elsewhere on the board
G7_3V3: U2.88 (D1/SO/IOR14A); also elsewhere on the board
G7_FPGA: U2.59 (IOB29B/GCLKC_4); also elsewhere on the board
GND: C4.1, C5.1, C14.1, C20.2, C34.1, C35.1, C43.2, J5.4, J6.1, R1.1, R2.1, R4.1, RN1.5 (R4.2), U2.2 (GND), U2.17 (GND), U2.33 (GND), U2.35 (GND), U2.53 (GND), U2.74 (GND), U2.89 (GND), U2.105 (GND), U2.107 (GND), U2.122 (GCLKC_1/IOT29B), U5.4 (VSS); also elsewhere on the board
HDMI_RESET: RN1.2 (R2.1), U2.15 (IOL12A/SCLK); also elsewhere on the board
HSYNC_3V3: U2.102 (RPLL_T_FB/IOR6A); also elsewhere on the board
HSYNC_FPGA: U2.34 (IOB6B); also elsewhere on the board
I2S0: R10.2; also elsewhere on the board
INT: RN1.1 (R1.1), U2.28 (IOL25B); also elsewhere on the board
LRCLK: R9.2; also elsewhere on the board
L_AUDIO: C6.1; also elsewhere on the board
MCLK: R11.2, U5.11 (MCLK); also elsewhere on the board
MODE0: R2.2, U2.144 (MODE0/IOT5A)
MODE1: R1.2, U2.143 (MODE1/IOT6B)
PCLK: R7.2; also elsewhere on the board
PDN_RESET_N: U2.29 (IOB4A), U5.13 (PDN)
PIXELSW_3V3: U2.101 (RPLL_C_FB/IOR6B); also elsewhere on the board
R0_3V3: U2.70 (IOB39A); also elsewhere on the board
R0_FPGA: U2.60 (IOB30A); also elsewhere on the board
R1_3V3: U2.71 (IOB39B); also elsewhere on the board
R1_FPGA: U2.61 (IOB30B); also elsewhere on the board
R2_3V3: U2.72 (IOB41A); also elsewhere on the board
R2_FPGA: U2.62 (IOB31A); also elsewhere on the board
R3_3V3: U2.75 (IOB42B); also elsewhere on the board
R3_FPGA: U2.63 (IOB31B); also elsewhere on the board
R4_3V3: U2.76 (IOB43B); also elsewhere on the board
R4_FPGA: U2.64 (IOB33A); also elsewhere on the board
R5_3V3: U2.78 (IOB43A); also elsewhere on the board
R5_FPGA: U2.65 (IOB33B); also elsewhere on the board
R6_3V3: U2.79 (IOR24B); also elsewhere on the board
R6_FPGA: U2.66 (IOB35A); also elsewhere on the board
R7_3V3: U2.80 (IOR23B); also elsewhere on the board
R7_FPGA: U2.67 (IOB35B); also elsewhere on the board
READY: RN2.1 (R1.1), U2.22 (IOL14B/READY)
RECONFIG_N: RN2.3 (R3.1), U2.20 (IOL13B/RECONFIG_N)
R_AUDIO: C7.1; also elsewhere on the board
SCL_I2C: U2.69 (IOB37B); also elsewhere on the board
SDA_I2C: U2.68 (IOB37A); also elsewhere on the board
TCK: J5.1, RN1.4 (R4.1), U2.14 (IOL11B/TCK)
TDI: J5.2, U2.16 (IOL12B/TDI)
TDO: J5.3, RN2.4 (R4.1), U2.18 (IOL13A/TDO)
TMS: J5.5, U2.13 (IOL11A/TMS)
VCC: C5.2, C35.2, R6.1, U5.5 (VA); also elsewhere on the board
VCC1V8: U2.9 (VCCIO3), U2.19 (VCCIO3); also elsewhere on the board
VSYNC_3V3: U2.104 (RPLL_C_IN/IOR5B); also elsewhere on the board
VSYNC_FPGA: U2.32 (IOB6A); also elsewhere on the board
XTAL_24.576M: U2.56 (IOB28A/GCLKT_5); also elsewhere on the board
XTAL_27M: U2.58 (IOB29A/GCLKT_4); also elsewhere on the board
XTAL_50M: U2.123 (GCLKT_1/IOT29A); also elsewhere on the board

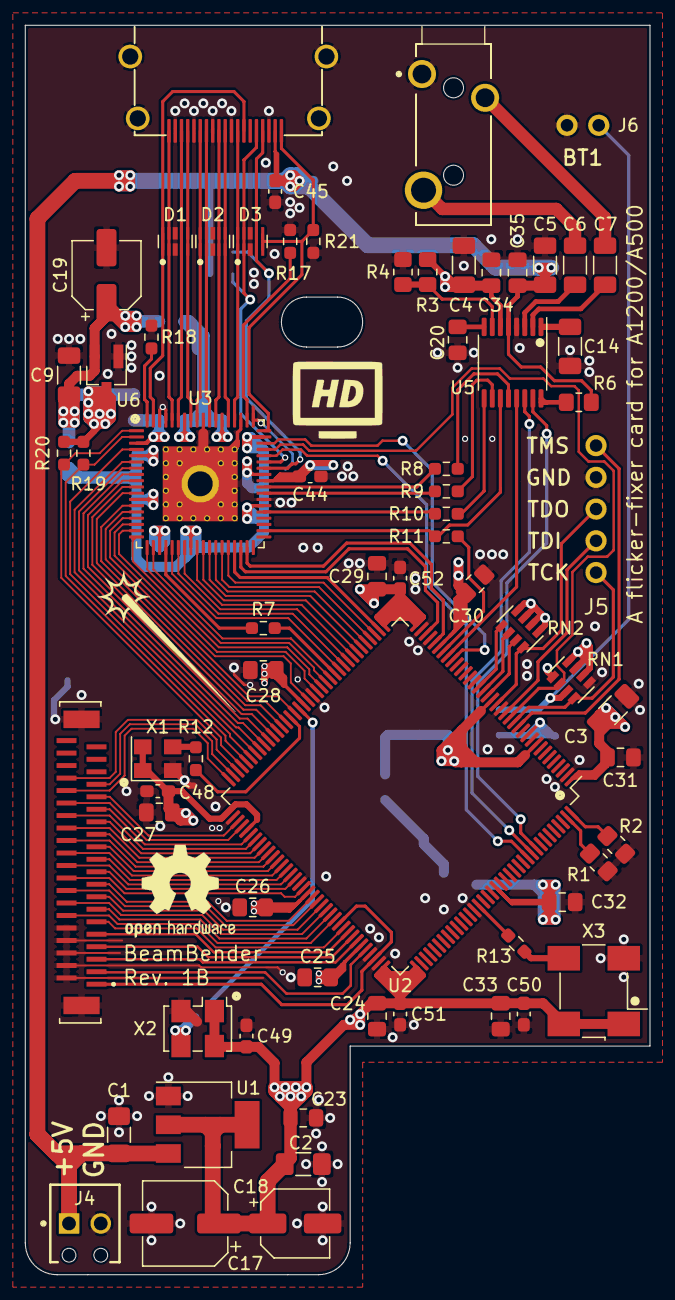
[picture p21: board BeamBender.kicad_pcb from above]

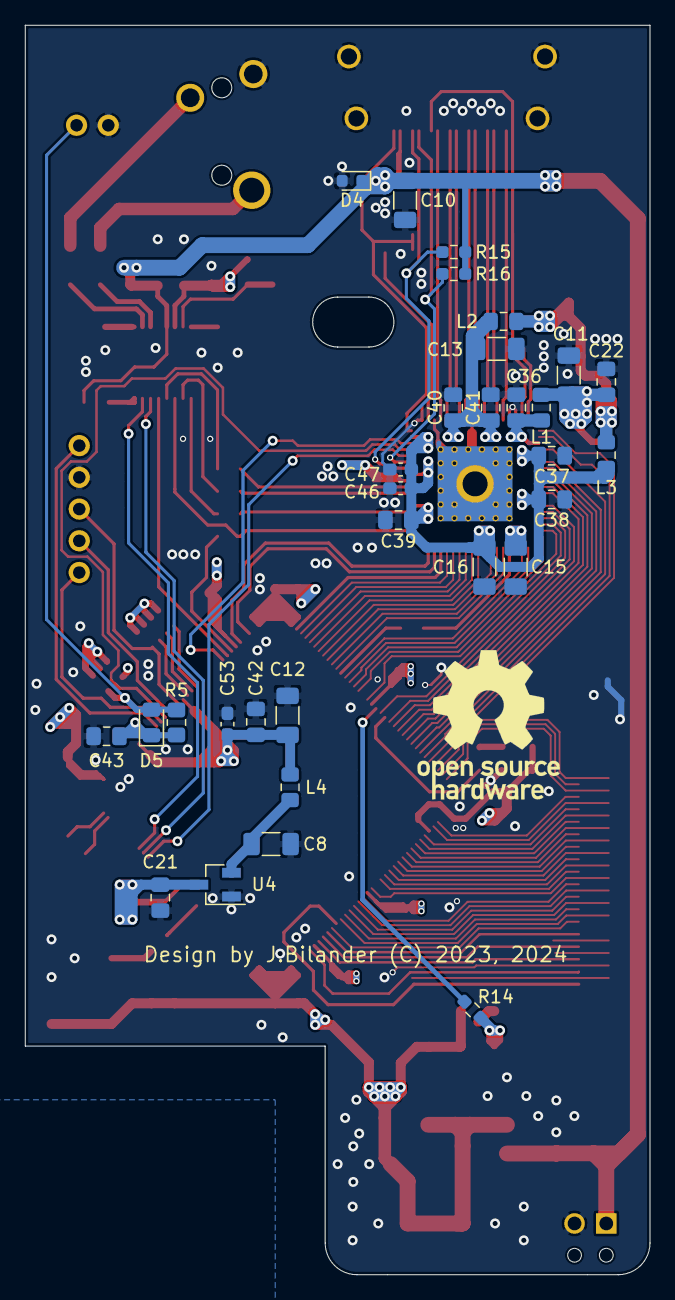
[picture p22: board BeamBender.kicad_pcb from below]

Board: 4 copper layers, 50.0 x 100.0 mm, 100 parts (31 on the bottom side), 122 nets.

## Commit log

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2023-09-19 Added KiCad files
    [BeamBender.kicad_pcb, BeamBender.sch]
2023-09-19 Renamed folder
    [BeamBender.kicad_pcb, BeamBender.sch]
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2023-09-20 Added a 3.5mm input audio jack
    [BeamBender.kicad_pcb, BeamBender.sch]
2023-10-01 Adjusted hole in middle to dedicated A1200-design
    [BeamBender.kicad_pcb]
2023-10-02 Moved mounting hole 1 mm up
    [BeamBender.kicad_pcb]
2023-10-05 Added ADV7513 HDMI-transmitter
    [BeamBender.kicad_pcb, BeamBender.sch]
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2023-10-05 Added 4 channel low capacitance TVS diode array D5V0F4U10MR
    [BeamBender.kicad_pcb, BeamBender.sch]
2023-10-05 Added two more TVS-diodes for ESD-protection and started routing the diff-pairs
    [BeamBender.kicad_pcb, BeamBender.sch]
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2023-10-06 more diff-pair routing
    [BeamBender.kicad_pcb, BeamBender.sch]
2023-10-06 more place and route
    [BeamBender.kicad_pcb, BeamBender.sch]
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2023-10-07 Added a Phoenix Contact for +5V power supply and did some place and route around the 3.3V-regulator
    [BeamBender.kicad_pcb, BeamBender.sch]
2023-10-08 Added Polarized electrolytical capacitors for 3V3-power
    [BeamBender.kicad_pcb, BeamBender.sch]
2023-10-08 Fixed power place and route due to height constraint
    [BeamBender.kicad_pcb]
2023-10-31 Added Gowin FPGA GW1NR-UV9LQ144P
    [BeamBender.kicad_pcb, BeamBender.sch, BeamBender_FPGA.sch]
2023-11-01 Added 27 MHz crystal oscillator X1 to GCLKT_4 pin and did some routing
    [BeamBender.kicad_pcb, BeamBender.sch, BeamBender_FPGA.sch]
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2023-11-02 Changed to four layer stackup, added some caps and done some more routing
    [BeamBender.kicad_pcb, BeamBender.sch, BeamBender_FPGA.sch]
2023-11-02 more place and route done
    [BeamBender.kicad_pcb, BeamBender.sch, BeamBender_FPGA.sch]
2023-11-02 more place and route of pull-ups for SDL,SDA,DDC_SDL and DDC_SDA around ADV7513 chip
    [BeamBender.kicad_pcb, BeamBender.sch]
2023-11-02 more routing done
    [BeamBender.kicad_pcb, BeamBender.sch, BeamBender_FPGA.sch]
2023-11-03 Added Oscillator_7.0x5.0mm X2 on GCLKT_1 input and added damping resistor on PCLK
    [BeamBender.kicad_pcb, BeamBender.sch, BeamBender_FPGA.sch]
2023-11-08 Added a 1.8V LDO (MCP1702T-1802E_CB) in SOT-23 for powering the ADV7513 with 1.8V (DVDD,AVDD,PVDD,BGVDD)
    [BeamBender.kicad_pcb, BeamBender.sch, BeamBender_FPGA.sch]
2024-02-05 More power routing done
    [BeamBender.kicad_pcb, BeamBender.sch]
2024-02-07 More routing of power supply
    [BeamBender.kicad_pcb, BeamBender.sch]
2024-02-08 More 1.8V power routing and caps placement
    [BeamBender.kicad_pcb, BeamBender.sch]
2024-02-19 More power routing done for 1.8V to ADV7513
    [BeamBender.kicad_pcb, BeamBender.sch]
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2024-02-20 Changed PD to pull-up instead of pull-down, fixed A1200 mounting hole and A500 cutout area
    [BeamBender.kicad_pcb, BeamBender.sch]
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2024-02-21 Breakout of own symbol for A500 drill-hole and more assignments of FPGA-pins
    [BeamBender.kicad_pcb, BeamBender.sch, BeamBender_FPGA.sch]
2024-02-21 Added 1k pull-down resistors on the FPGA's MODE0 and MODE1 pins
    [BeamBender.kicad_pcb, BeamBender_FPGA.sch]
2024-02-21 Added JTAG-pinheader and pull-up resistor arrays
    [BeamBender.kicad_pcb, BeamBender_FPGA.sch]
2024-02-23 Fixed JTAG-connector and remaining 3V3-power routing and pull-ups for FPGA
    [BeamBender.kicad_pcb, BeamBender.sch, BeamBender_FPGA.sch]
2024-02-24 Added RC-debounce circuit to Button 1 (BT1)
    [BeamBender.kicad_pcb, BeamBender_FPGA.sch]
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2024-02-26 added a 24.576 MHz crystal oscillator 5.0x3.2mm for Audio MCLK routed to FPGA pin 98 (GCLKT_2)
    [BeamBender.kicad_pcb, BeamBender_FPGA.sch]
2024-02-26 Added series resistors to BCLK, LRCLK and I2S0 audio lines.
    [BeamBender.kicad_pcb, BeamBender_FPGA.sch]
2024-02-27 Fixed the symbol for 3.5mm phono jack (STX-3501-3N) to be more clear with regards to TRS (Tip,Ring,Sleeve) pinout
2024-02-27 assigned the audio Left and Right channels to 3.5mm phono jack (STX-3501-3N) and to ADC-chip (AK5720)
    [BeamBender.kicad_pcb, BeamBender.sch, BeamBender_FPGA.sch]
2024-02-27 Added coupling caps for analogue left and right channel to inputs on ADC-chip (AK5720VT)
    [BeamBender.kicad_pcb, BeamBender_FPGA.sch]
2024-02-27 Added a 0.47uF cap for ADC-chip VCOM pin (Voltage Reference)
    [BeamBender.kicad_pcb, BeamBender_FPGA.sch]
2024-02-29 Repositioning of the AK5720 chip and routed the analog supply with 5V and digital supply with 3V3
    [BeamBender.kicad_pcb, BeamBender_FPGA.sch]
2024-02-29 Added a pull-up resistor for GSEL (Gain-Select) input pin with a solder JP to be able to turn gain off = GND
    [BeamBender.kicad_pcb, BeamBender_FPGA.sch]
2024-03-02 Finished routing the ak5720vt-chip, changed to a potential-divider for controlling GSEL-pin, PDN_RESET,FSEL and DIF-signals routed to spare pins in the FPGA
    [BeamBender.kicad_pcb, BeamBender_FPGA.sch]
2024-03-05 Fixed assignment/enumeration of all capacitors from C1 to C54
    [BeamBender.kicad_pcb, BeamBender.sch, BeamBender_FPGA.sch]
2024-03-06 Some silkscreen text fixes and OSHW-logos placement done
    [BeamBender.kicad_pcb]
2024-03-06 Fixed enumeration/order of all resistors on board and their reference placement on silkscreen
    [BeamBender.kicad_pcb, BeamBender.sch, BeamBender_FPGA.sch]
2024-03-06 Fixed ordering of L1-L4, changed R14-R21 to 33 Ohms, and swapped X2 and X3 reference
    [BeamBender.kicad_pcb, BeamBender.sch, BeamBender_FPGA.sch]
2024-03-07 Silkscreen fix
    [BeamBender.kicad_pcb]
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2024-03-07 small routing fix
    [BeamBender.kicad_pcb]
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2024-03-10 Changed R12 to a selectable pull-up/pull-down three-pads footprint
    [BeamBender.kicad_pcb, BeamBender.sch]
2024-03-11 Added some GND via-stitching for the FPGA
    [BeamBender.kicad_pcb]
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2024-05-27 Adapted design to take 1.8V on VCCIO3 because of embedded pSRAM requirement, changed RN1, RN2 to 4.7k Ohm, relocated pin FSEL and DIF/TDMI to bank0, moved PDN_RESET_N to pin 29 and MCLK to pin 30. JP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
    [BeamBender.kicad_pcb, BeamBender.sch, BeamBender_FPGA.sch]
2024-05-28 Added decoupling cap C55 (10nF 0603) to VCCIO3-input (DVDD)
    [BeamBender.kicad_pcb, BeamBender.sch]
2024-05-28 changed R12 from Resistor-jumper to pull-down only for PD-line
    [BeamBender.kicad_pcb, BeamBender.sch]
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2024-07-22 Moved the Phoenix-connector J4 and cap C17 a bit to the right
    [BeamBender.kicad_pcb]
2024-07-23 Small improvement of routing VCC1V8 to VCCIO3-pins on the FPGA
    [BeamBender.kicad_pcb]
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2024-07-23 Added SP1003-01DTG TVS-Diode for ESD-protection of VCC-line
    [BeamBender.kicad_pcb, BeamBender.sch, BeamBender_FPGA.sch]
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2024-07-28 Fixed pin 1 indicator adding a dot on silkscreen
    [BeamBender.kicad_pcb]
2024-07-29 Silkscreen fixes
    [BeamBender.kicad_pcb]
2024-07-29 Placed net label for EXT_SWING
    [BeamBender.kicad_pcb, BeamBender.sch]
2024-09-07 small silkscreen and GND fix
    [BeamBender.kicad_pcb]
2024-09-10 fixed U-enumeration, changed U7 to U6
    [BeamBender.kicad_pcb, BeamBender.sch]

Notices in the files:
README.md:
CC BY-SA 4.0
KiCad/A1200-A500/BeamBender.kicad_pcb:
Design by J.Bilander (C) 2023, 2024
